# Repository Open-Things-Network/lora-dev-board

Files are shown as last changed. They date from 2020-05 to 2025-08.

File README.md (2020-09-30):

# lora-dev-board

Uniwersalna platforma sprzętowa ułatwiająca projektowanie i testowanie urządzeń IoT wykorzystujących do komunikacji sieć LoRaWAN.

## Cele projektu

* Udostępnienie gotowego do wykorzystania projektu płytki PCB
* Dostarczenie przykładowych szablonów aplikacji pozwalających na programowanie płytki przy użyciu Arduino SDK

## Założenia

Platforma została zaprojektowana tak, aby jej zbudowanie i uruchomienie było możliwe dla hobbystów posiadających podstawowe umiejętności w zakresie budowanie układów elektronicznych oraz programowania. Zgodnie z tym  przyjęto też dodatkowe założenia: 

* Zastosowanie popularnej płytki Arduino Pro Mini z mikrokontrolerem ATmega328P
* Współpraca z najczęściej stosowanymi układami nadawczo-odbiorczymi LoRa: RFM95W lub RN2483
* Wykorzystanie różnych źródeł zasilania, w tym standardowych baterii alkalicznych, baterii litowych oraz akumulatorów litowo-polimerowych lub litowo-jonowych
* Możliwość ładowania baterii litowo-polimerowych lub litowo-jonowych z wykorzystaniem paneli fotowoltaicznych małej mocy lub poprzez gniazdo USB

## Jak zacząć?

W `templates` znajdują się szablony aplikacji, które z pewnością ułatwią realizację własnych pomysłów, a folder `projects` zawiera przykłady projektów zrealizowanych z wykorzystaniem platformy **lora-dev-board**.

Poniższe punkty zostaną wkrótce uzupełnione opisami.

* Projekt płytki: [kompletacja elementów](https://github.com/Open-Things-Network/lora-dev-board/blob/master/v1.0/README.md#lista-elementów) i budowa urządzenia
* Uruchomienie bazowej aplikacji wysyłającej informacje o stanie urządzenia

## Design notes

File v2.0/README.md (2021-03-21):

# v2.0

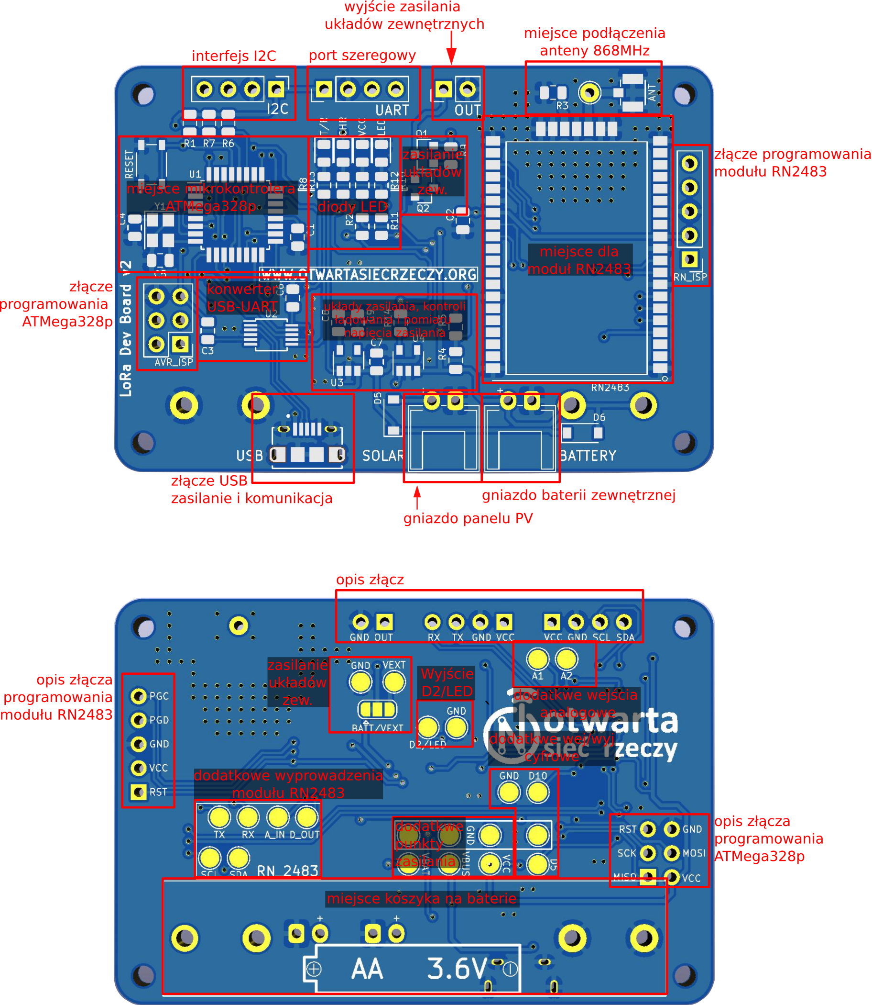
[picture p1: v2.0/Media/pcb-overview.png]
pcb overview


# Spis treści:
1. [Opis płytki](#Opis-płytki)
2. [Bootloader](#Bootloader)
3. [Interfejs LoRaWAN](#Interfejs-LoRaWAN)
4. [Układ zasilania](#Układ-zasilania)
5. [Układ ładowania](#Układ-ładowania)
6. [Diody LED](#Diody-LED)
7. [Interfejsy komunikacyjne](#Interfejsy-komunikacyjne)
8. [Złącza zasilania](#Złącza-zasilania)
9. [Pomiar napięcia baterii](#Pomiar-napięcia-baterii)
10. [Sterowanie zasilaniem układów zewnętrznych](#Sterowanie-zasilaniem-układów-zewnętrznych)
11. [Lista elementów](#Lista-elementów)
12. [Uwagi](#Uwagi)

# Opis płytki
Platforma deweloperska oparta na mikrokontrolerze ATMega328p. Na płytce znajduje się konwerter USB-UART dzięki czemu nie są wymagane dodatkowe układy komunikacyjne do programowania.
Do komunikacji z siecią LoRaWAN służy moduł RN2483.

## Bootloader
Do mikrokontrolera wgrany jest bootloader z Arduino Pro Mini za pomocą złącz programowania ISP, dzięki czemu można przygotować oraz wgrać program przez ARDIUNO IDE lub PLATFORMIO wykorzystując konwerter USB-UART.

## Interfejs LoRaWAN
Płytka pozwala na realizację interfejsu LoRaWAN za pomocą modułu z wbudowaną obsługą stosu LoRaWAN [RN2483A](https://www.microchip.com/wwwproducts/en/RN2483) - komunikacja z modułem poprzez port szeregowy obsługiwany programowo przez piny 10 (RX) i 11 (TX) mikrokontrolera ATMega328p (odpowiednio piny 6 i 7 zgodnie z Arduino Pro Mini).

## Układ zasilania
Zastosowany regulator napięcia LDO [AP2112K-3.3TRG1](https://cdn-shop.adafruit.com/product-files/2471/AP2112.pdf).
* Maksymalne napięcie zasilania - 6V
* Minimalne napięcie zasilania - 2.5V
* Spadek napięcia dla prądu 10mA - 5mV, 300mA - 125mV, 600mA - 250mV
* Napięcie wyjściowe - 3.3V
* Prąd maksymalny - 1A

## Układ ładowania
Zastosowany kontroler ładowania akumulatorów litowo-polimerowych (Li-Po) i litowo-jonowych (Li-Ion) [MCP73831](https://www.microchip.com/wwwproducts/en/en024903#additional-features).
* Maksymalne napięcie zasilania - 6V
* Minimalne napięcie zasilania - 3.75V
* Napięcie ładowania - 4.2V
* Prąd ładowania reguluje się przez dobranie R1, dla 2k&#x2126; - 500mA, 4k&#x2126; - 250mA

## Diody LED
|Oznaczenie|Opis|
|:---:|:---|
|T/R|dioda sygnalizująca komunikację USB-ATMEGA|
|CHR|sygnalizuje ładowanie podłączonej baterii Li-Po/Li-Ion|
|VCC|sygnalizuje obecność napięcia zasilania|
|LED|dioda do ogólnego zastosowania w aplikacji użytkownika (`USER_LED`)|

## Interfejsy komunikacyjne
Do podłączenia zewnętrznych czujników dostępne są interfejsy:
* I2C (na magistrali wlutowane są rezystory podciągające)
* port szeregowy obsługiwany programowo (z wykorzystaniem biblioteki `SoftwareSerial`) na pinach 12 (RX) i 13 (TX) ATMega328p (odpowiednio piny 8 i 9 zgodnie z Arduino Pro Mini).

## Złącza zasilania
Do płytki możemy podłączyć źródło zasilania:
* USB - złącze USB pełni funkcje zasilania płytki, źródła ładowania baterii oraz komunikację z mikrokontrolerem.
* BATTERY - złącze baterii/akumulatorów Li-Po/Li-Ion 3,6V, do złącza podłczony jest kontoler ładowania akumulatorów.
* KOSZYK - miejsce na koszyk baterii/akumulatorów Li-Po/Li-Ion o rozmiarze AA (14500) 3,6V, do złącza podłczony jest kontoler ładowania akumulatorów.
* SOLAR - może służyć jako źródło zasilania, ale najlepiej można go wykorzystać wraz z ogniwem jako źródło ładowania akumulatora. Należy wykorzystać panel o napięciu 5,5V.

> **UWAGA!** Przy wykorzystaniu baterii litowych (FR6) nie ładowalnych należy wylutować kontroler ładowania akumulatorów U4.

## Pomiar napięcia baterii
Wykorzystane wejście analogowe A0 i dzielnik napięcia R4, R5 (makro `VBAT`).

## Sterowanie zasilaniem układów zewnętrznych
Układ sterowania jest złożony z dwóch tranzystorów. Pierwszy tranzystor NPN BC817 jest wysterowany z mikrokontrolera i wykorzystany jest do kluczowania drugiego tranzystora. Tranzystor polowy z kanałem typu P pozwala na sterowanie zasilaniem zewnętrznego urządzenia. Wybór zasilania dla zewnętrznego urządzenia dokonuje się zworką JP5(BATT/VEXT). Możemy zasilać urządzenie z stabilizowanego zasilania 3.3V lub zasilanie podać z zewnątrz (lub innego punktu), wymaga to podłączenia napięcia na pad VEXT oraz rozcięcie zworki JP5 i zalutowaniu jej w pozycji EXT. Zastosowany tranzystor polowy YJL2301F pozwala na obciążenie do 2A z źródła zewnętrznego oraz 600mA z VCC (ograniczenia wynikają z parametrów LDO). 

# Lista elementów
| Oznaczenie | Element | Obudowa | Ilość na PCB |
|:-----:|:---|:---|:--|
|KOSZYK|2915 keystone|n.d.|2|
|C1-C3;C6|100nF|0805|4|
|C4-C5|22pF|0805|2|
|C7|1uF|0805|1|
|C8|n.d.|0805|1|
|D1|LED YELLOW|0805|1|
|D2|LED GREEN|0805|1|
|D3|LED RED|0805|1|
|D4|LED BLUE|0805|1|
|D5-D6|1N5819|SOD-123|2|
|J1|u.FL|n.d.|1|
|J2;J5|PinHeader|1x04|2|
|J3|PinHeader|2x03|1|
|J4|PinHeader|1x05|1|
|J6|PinHeader|1x02|1|
|J7-J8|JST|PH-S2B|2|
|J9|USB|10118194-0001LF AMPHENOL|n.d.|1|
|Q1|YJL2301F|SOT-23|1|
|Q2|BC817|SOT-23|1|
|R1-R2;R6-R7;R9|10k|0805|5|
|R3|50R|0805|1|
|R5|33k|0805|1|
|R8;R10-R13|1k|0805|5|
|R14|4k|0805|1|
|SW1|SKRPACE010|n.d.|1|
|U1|ATMega328p-AU|TQFP-32|1|
|U2|CH340E|MSOP-10|1|
|U3|AP2112K-3.3|SOT-23-5|1|
|U4|MCP73831-2-OT|SOT-23-5|1|
|Y1|16MHz|3225|1|

# Uwagi
Na pierwszych wersjach płytki pojawił się błąd w opisie elementów Q1 i Q2. Każdy kto otrzyma taką wersję płytki zostanie o tym poinformowany.

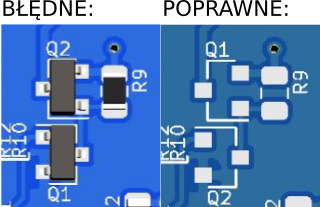
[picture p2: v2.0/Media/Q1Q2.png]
Front Silk Update


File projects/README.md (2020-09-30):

Projekty zrealizowane z wykorzystaniem platformy lora-dev-board.

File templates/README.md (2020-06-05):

# Szablony aplikacji

Zastosowanie szablonów ma na celu przyspieszenie procesu tworzenia własnych aplikacji. Wystarczy dokonać wstępnej parametryzacji i skupić się na implementacji docelowych funkcjonalności. Szablony aplikacji zapewniają realizację komunikacji LoRaWAN, wprowadzanie układu w stan uśpienia oraz ułatwiają wykorzystanie zasobów platformy w wybranym wariancie konfiguracji. 

Dostępne wersje szablonów:
* `lorawan-rfm-template.ino` - dla wariantu 1 konfiguracji (Arduino Pro Mini i RFM95W)
* `lorawan-rn-template.ino` - dla wariantu 2 konfiguracji (Arduino Pro Mini i RN2483A)

## Wymagania związane z oprogramowaniem
Wykorzystane biblioteki:
* [Arduino-LMIC Library](https://github.com/matthijskooijman/arduino-lmic)
* [Low Power Library for Arduino](https://github.com/rocketscream/Low-Power)
* [Cayenne LPP](https://github.com/ElectronicCats/CayenneLPP) lub [The Things Network Arduino Library](https://github.com/TheThingsNetwork/arduino-device-lib), która zawiera CayenneLPP i jest również używana do komunikacji z RN2483A

## Komunikacja LoRaWAN
### Zastosowanie RFM95W
Komunikacja mikrokontrolera z układem SX1276 (nadajnik-odbiornik LoRa), który znajduje się na płytce RFM95W jest realizowana poprzez interfejs SPI. Szczegółowe informacje dotyczące transceivera SX1276 można znaleźć w [dokumentacji układu](https://semtech.my.salesforce.com/sfc/p/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).

Moduł RFM95W jest połączony z Arduino Pro Mini w następujący sposób:

|RFM95W|Arduino Pro Mini|
|:----:|:---:|
|MOSI|11 (MOSI)|
|MISO|12 (MISO)|
|SCK|13 (SCK)|
|NSS|10|
|RESET|4|
|DIO0|5|
|DIO1|7|
|DIO2|6 (opcja - patrz JP3)|

Za realizację stosu LoRaWAN odpowiada biblioteka [Arduino-LMIC Library](https://github.com/matthijskooijman/arduino-lmic).

Pierwszym krokiem jest poinformowanie biblioteki, które piny Arduino zostały użyte do realizacji komunikacji z transceiverem.
Mapowanie pinów zgodnie z przedstawioną powyżej listą połączeń:
```c
const lmic_pinmap lmic_pins = {
    .nss = 10,
    .rxtx = LMIC_UNUSED_PIN,
    .rst = 4,
    .dio = { 5, 7, LMIC_UNUSED_PIN }, // lub { 5, 7, 6 } jeśli ma być wykorzystany również DIO2
};
```
> LMIC potrzebuje dostępu do DIO0, DIO1 i opcjonalnie DIO2. Wykorzystanie DIO2 dotyczy tylko pracy z modulacją FSK. W przypadku modulacji LoRa używane są DIO0 i DIO1.

Kolejnym krokiem jest przekazanie informacji o sposobie aktywacji urządzenia w sieci.
W szablonie użyto aktywacji według personalizacji (ABP - *Activation By Personalization*). Jest to najprostszy sposób aktywacji wykorzystywany do realizacji urządzenia podłączonego na stałe do jednej wybranej sieci. Urządzenie jest gotowe do pracy zaraz po rejestracji w sieci. Proces rejestracji urządzenia w sieci The Things Network jest dobrze opisany w [dokumentacji](https://www.thethingsnetwork.org/docs/devices/registration.html). Podczas rejestracji należy pamiętać o wybraniu metody aktywacji ABP.

Urządzenie posiada stały adres (*Device Address*) i zestaw kluczy sesyjnych wykorzystywanych do sprawdzania integralności wiadomości w warstwie sieci (*Network Session Key*) oraz do szyfrowania danych w warstwie aplikacji (*Application Session Key*). Urządzenie jest więc aktywowane na etapie personalizacji i zarówno adres urządzenia, jak i klucze sesji nie zmieniają się przez cały czas pracy urządzenia.<br>
Informacje uzyskane podczas rejestracji urządzenia należy wstawić w miejsce właściwych stałych:
```c
static const PROGMEM u1_t NWKSKEY[16] = { 0x00, 0x00, 0x00, 0x00, 0x00, 0x00, 0x00, 0x00, 0x00, 0x00, 0x00, 0x00, 0x00, 0x00, 0x00, 0x00 };
static const PROGMEM u1_t APPSKEY[16] = { 0x00, 0x00, 0x00, 0x00, 0x00, 0x00, 0x00, 0x00, 0x00, 0x00, 0x00, 0x00, 0x00, 0x00, 0x00, 0x00 };
static const u4_t DEVADDR = 0x00000000;
```
Stosowanie ABP jest mniej bezpieczne i nie jest zlecane również ze względu na ograniczenia funkcjonalne, lecz brak konieczności nawiązywania i sprawdzania połączenia z siecią może być w pewnych zastosowaniach zaletą. 

Komunikacja bezprzewodowa urządzenia z bramkami LoRaWAN odbywa się w kanałach, których środek wyznaczają ściśle określone częstotliwości. Zwykle używa się ośmiu kanałów o szerokości 125kHz, z których trzy są obowiązkowe i niezależne od sieci, a pozostałe są opcjonalne i mogą być określone indywidualnie dla każdej sieci, przy zachowaniu właściwej separacji i zasad określonych w zaleceniach dotyczących pasma.<br>
W przypadku sieci TTN stosowane są następujące kanały:
```c
// obowiązkowe
LMIC_setupChannel(0, 868100000, DR_RANGE_MAP(DR_SF12, DR_SF7), BAND_CENTI); 
LMIC_setupChannel(1, 868300000, DR_RANGE_MAP(DR_SF12, DR_SF7), BAND_CENTI); 
LMIC_setupChannel(2, 868500000, DR_RANGE_MAP(DR_SF12, DR_SF7), BAND_CENTI); 
// dodatkowe
LMIC_setupChannel(3, 867100000, DR_RANGE_MAP(DR_SF12, DR_SF7), BAND_CENTI); 
LMIC_setupChannel(4, 867300000, DR_RANGE_MAP(DR_SF12, DR_SF7), BAND_CENTI);
LMIC_setupChannel(5, 867500000, DR_RANGE_MAP(DR_SF12, DR_SF7), BAND_CENTI); 
LMIC_setupChannel(6, 867700000, DR_RANGE_MAP(DR_SF12, DR_SF7), BAND_CENTI);
LMIC_setupChannel(7, 867900000, DR_RANGE_MAP(DR_SF12, DR_SF7), BAND_CENTI);
```
Jest jeszcze jeden dedykowany kanał (869.525MHz) o szerokości 125kHz, który służy tylko do przesyłania informacji w kierunku do urządzenia (*downlink*) w tzw. drugim oknie odbiorczym RX2. 
Parametry transmisji w tym kanale są stałe i ustawione domyślnie na SF12, czyli DR0 (*Data Rate 0*). W przypadku sieci TTN parametr ten powinien być zmieniony na SF9 (DR2):
```c 
LMIC.dn2Dr = DR_SF9;
```
To wystarczy żeby rozpocząć komunikację z wykorzystaniem The Things Network - otwartej sieci LoRaWAN.

LMIC oferuje prosty model programowania oparty na zdarzeniach, w którym wszystkie zdarzenia protokołu są wysyłane do funkcji zwrotnej `onEvent()`.
W tym modelu cały kod aplikacji jest uruchamiany w tak zwanych zadaniach (funkcjach), które są wykonywane w głównym wątku za pomocą harmonogramu `os_runloop_once()`. Do zarządzania zadaniami wymagana jest dodatkowa struktura typu `osjob_t`, która identyfikuje zadanie i przechowuje informacje kontekstowe. Przykładem zadania w opisywanym szablonie jest funkcja `do_send()` odpowiadająca za przygotowanie i  wysyłanie danych. Zadanie to jest wykonywane cyklicznie co określony interwał (`TX_INTERVAL`). Wysyłanie danych z urządzenia do sieci jest inicjowane wywołaniem funkcji `LMIC_setTxData2()`. Zakończenie wysyłania danych jest sygnalizowane wystąpieniem zdarzenia `EV_TXCOMPLETE` obsługiwanego w `onEvent()`. W tym miejscu planowane jest kolejne wykonanie zadania poprzez wywołanie `os_setTimedCallback()`. Można również sprawdzić, czy zostały odebrane informacje zwrotne przesłane z sieci do urządzenia.    

Wywołanie poniższej funkcji powoduje kompensację błędów zegara i opóźnień wprowadzanych przez program, co w rezultacie zwiększa szansę odebrania informacji zwrotnej przesyłanej do urządzenia w wyznaczonych oknach czasowych (dokładny opis problemu znajduje się w [dokumentacji LMIC](https://github.com/matthijskooijman/arduino-lmic#timing)).
```c 
LMIC_setClockError(MAX_CLOCK_ERROR * 1 / 100);
```

Ustawianie parametru DR (*Data Rate*) oraz mocy nadajnika umożliwia funkcja `LMIC_setDrTxpow()`. Przykład użycia tej funkcji w celu ustawienia DR0 (SF7) i mocy nadajnika na poziomie 14dBm (czyli 25mW):
```c
LMIC_setDrTxpow(DR_SF7, 14);
```

Fragment kodu przedstawiony poniżej wyłącza tryb sprawdzania połączenia z siecią, który w przypadku ABP nie ma praktycznie zastosowania.
```c
LMIC_setLinkCheckMode(0);
```

Jeśli aplikacja wykorzystuje ABP, a urządzenie nie pracuje w klasie B, to warto zaoszczędzić trochę zasobów wyłączając część kodu odpowiedzialną za obsługę nieużywanych funkcjonalności. Można tego dokonać poprzez odkomentowanie następujących definicji w pliku `src/lmic/config.h` biblioteki LMIC:
```c
// Uncomment this to disable all code related to joining
#define DISABLE_JOIN
// Uncomment this to disable all code related to ping
#define DISABLE_PING
// Uncomment this to disable all code related to beacon tracking.
// Requires ping to be disabled too
#define DISABLE_BEACONS
```
W ten sposób można zyskać nawet kilka kilobajtów pamięci programu. Dzięki temu można również usunąć z aplikacji nieużywane funkcje (ich brak nie będzie już generował błędów podczas kompilacji):
```c
void os_getArtEui (u1_t* buf) { }
void os_getDevEui (u1_t* buf) { }
void os_getDevKey (u1_t* buf) { }
```
### Zastosowanie RN2483
Do uzupełnienia.
## Interwał wysyłania danych
Czas pomiędzy kolejnymi próbami wysyłania danych do sieci LoRaWAN (*uplink*) określa stała `TX_INTERVAL`. Wartość domyślna, to 60 sekund. 
```c
const unsigned TX_INTERVAL = 60;
```
Należy pamiętać o obowiązujących ograniczeniach dotyczących zajętości pasma. Zasady dostępu do kanału (tzw. cykl pracy nadajnika - *Duty Cycle*) oraz dopuszczalna moc sygnału nadawanego są ściśle określone w stosownych normach. W Europie sposób wykorzystania pasma otwartego 868MHz określa norma ETSI EN 300 220.<br>
Zarówno LMIC, jak i stos LoRaWAN zaimplementowany w układzie RN2483A uwzględniają te ograniczenia, a każda próba wysłania wiadomości, która narusza zasady zakończy się błędem (`no_free_ch` w przypadku RN2483A).<br>
W sieci The Things Network obowiązują również dodatkowe limity związane z czasem nadawania (tzw. *Fair Access Policy*). 

Wszystkie te ograniczenia są opisane w [dokumentacji TTN](https://www.thethingsnetwork.org/docs/lorawan/duty-cycle.html).

## Rodzaj i format danych
W szablonach został wykorzystany popularny sposób kodowania danych [Cayenne LPP (*Low Power Payload*)](https://developers.mydevices.com/cayenne/docs/lora/#lora-cayenne-low-power-payload), który znacząco upraszcza przygotowanie i wysyłanie danych. Wadą stosowania Cayenne LPP jest zwiększony rozmiar przesyłanych danych, ponieważ do każdej wartości dodawane są informacje określające identyfikator kanału oraz typ danych.

Przykład użycia Cayenne LPP:
```c
#include <CayenneLPP.h>
```
* utworzenie bufora o długości 51 bajtów
```c
CayenneLPP lppdata(51);
```
* wyczyszczenie bufora i dodanie pierwszej wartości (w tym przypadku wartość napięcia baterii, kanał 1)
```c
lppdata.reset();
lppdata.addAnalogInput(1, VBAT);
```
> Podstawowa wersja Cayenne LPP umożliwia kodowanie jedynie 12 typów danych. Jeśli brakuje typu odpowiedniego dla określonej wielkości mierzonej, to można zastosować wejście analogowe (`LPP_ANALOG_INPUT`). Takie rozwiązanie zostało wykorzystane w szablonach do przesyłania wartości napięcia elektrycznego. 
* wysłanie danych z wykorzystaniem `getBuffer()` i `getSize()` w celu wskazania miejsca przechowywania i określenia ilości danych
```c
LMIC_setTxData2(1, lppdata.getBuffer(), lppdata.getSize(), 0); 
```
Odbierane dane mogą być automatycznie dekodowane po stronie aplikacji zdefiniowanej w TTN bez konieczności tworzenia własnego dekodera (wystarczy zmienić **Payload Format** z `Custom` na `Cayenne LPP`).<br>
Przykład zdekodowanej wiadomości:
```
{
  "analog_in_1": 3.77
}
```
Zastosowanie dyrektywy
```c
#define JUST_SEND_HELLO
```
powoduje, że urządzenie wysyła tylko wiadomość o treści `"Hello!"`. 
## Oszczędzanie energii
Szablony zawierają przykład prostej realizacji wprowadzania urządzenia w stan uśpienia w celu wydłużenia czasu pracy na baterii. Do tego celu wykorzystana została popularna biblioteka [Low Power](https://github.com/rocketscream/Low-Power) dla Arduino, która jest bardzo łatwa w użyciu dla początkującego programisty. Biblioteka dostarcza zestaw metod służących do wprowadzania mikrokontrolera w określony tryb uśpienia (*Sleep Mode*) z możliwością wyłączenia poszczególnych jego komponentów na określony czas. 
```c
#include <LowPower.h>
```
Włączenie trybu oszczędzania energii w programie odbywa się poprzez zastosowanie dyrektywy `SAVE_ENERGY`.
```c
#define SAVE_ENERGY
``` 
W programie wykorzystano metodę `powerDown()`, która wprowadza mikrokontroler w stan wyłączenia (*Power Down*). Jest to tryb maksymalnego oszczędzania energii, w którym wykorzystywana jest minimalna liczba zintegrowanych układów peryferyjnych potrzebna do wznowienia pracy mikrokontrolera - w tym przypadku przerwanie z WDT (*Watchdog Timer*). Wywołanie tej metody z parametrami jak poniżej powoduje wyłączenie mikrokontrolera na czas 8 sekund.
```c
LowPower.powerDown(SLEEP_8S, ADC_OFF, BOD_OFF);
```
## Wykorzystanie zasobów platformy
### Pomiar napięcia baterii
Napięcie baterii zostało doprowadzone do dzielnika napięcia, którego wyjście jest podłączone do wejścia analogowego A0 modułu Arduino Pro Mini. Makro `VBAT` zwraca wartość napięcia baterii wyrażoną w woltach. 
```c
#define VBAT (analogRead(A0) * 0.00424568)
```
Zastosowana stała wynika z wartości rezystancji użytych do budowy dzielnika oraz wartości napięcia wewnętrznego źródła referencyjnego. 
### Obsługa portu szeregowego
Oprócz sprzętowego portu szeregowego modułu Arduino Pro Mini (używanego również do programowania i debugowania), płytka udostępnia dodatkowy port obsługiwany programowo dzięki zastosowaniu standardowej biblioteki `SoftwareSerial`. Port ten jest podpięty pod piny 8 (RX) i 9 (TX) Arduino Pro Mini. Wyprowadzenie sygnałów na złącze J3 (UART) pozwala na podłączenie dodatkowych urządzeń zewnętrznych (np. odbiornika GPS).

```c
SoftwareSerial userSerial(8, 9); // GPSP available on J3 (RX, TX)  
...
userSerial.begin(9600);
```
### Wykorzystanie diody LED
Na płytce można zamontować dodatkową diodę LED podłączoną do pinu 2 Arduino Pro Mini.
```c
#define USER_LED 2 // additional LED
```
Dioda ta może być wykorzystana w aplikacji w dowolny sposób.
W prezentowanych szablonach służy jako wskaźnik komunikacji LoRaWAN - jest włączana przed zainicjowaniem wysyłania danych i wyłączana po zakończeniu cyklu transmisji i odbioru danych. 

Sterowanie diodą LED:
```c
pinMode(USER_LED, OUTPUT);
...
digitalWrite(USER_LED, HIGH);
digitalWrite(USER_LED, LOW);
```
### Sterowanie zasilaniem układów zewnętrznych
Układ zasilania urządzeń zewnętrznych zbudowany z tranzystorów Q1 i Q2 został podłączony do pinu 3 modułu Arduino Pro Mini. Układ ten zapewnia odpowiednią wydajność prądową, a także umożliwia sterowanie obecnością napięcia na padach TP5 (VOUT) i TP6 (GND). W zależności od zworki JP9 będzie to napięcie z układu regulatora (VCC) lub napięcie baterii (VBAT). 

Sterowanie zasilaniem urządzeń zewnętrznych z poziomu aplikacji odbywa się poprzez ustawianie odpowiedniego stanu na wyjściu `VOUT_ENABLE`. 
```c
#define VOUT_ENABLE 3 
```
Przykład realizacji sterowania:
```c
pinMode(VOUT_ENABLE, OUTPUT);
...
digitalWrite(VOUT_ENABLE, HIGH);
digitalWrite(VOUT_ENABLE, LOW);
```

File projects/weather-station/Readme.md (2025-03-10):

# Stacja pogody

*For English version go [here](Readme_eng.md)*

Projekt bazuje na kodzie napisanym na platformie arduino w pliku `weather-station.ino`. Wykorzystuje wersję v2.0 płytki PCB.
Aby skonfigurować projekt należy edytowac zmienne `appEui` oraz `appKey` zgodnie z ustawieniami sieci TTN. Transceiver będzie korzystał z trybu OTAA.

## Kompilacja i wgrywanie

Kompilację projektu wykonuje się poprzez Arduino IDE. Aby wgrać kod na płytkę należy skorzystac z gniazda USB znajdującego się na płytce PCB.

## Obudowa

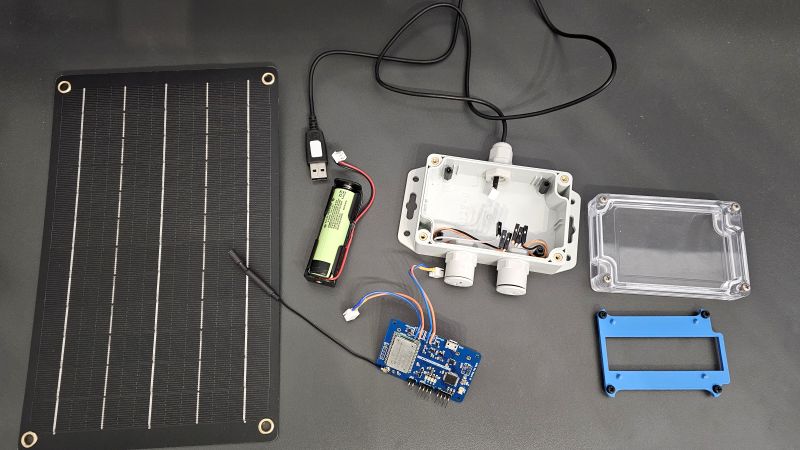
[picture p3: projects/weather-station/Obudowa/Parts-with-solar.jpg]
Obudowa


Lista części: 
- Obudowa: Kradex Z128
- Panel słoneczny: DFRobot FIT0601
- Czujniki: DS18B20 & BME280
- Bateria: Panasonic NCR18650B
- Inne części:
    - Dławnice kablowe M12 x3
    - Dystanse 12 mm x4
- Antena: 868 Mhz w kształcie sprężyny ze złączem U.FL.

Dodatkowo potrzebny jest wydruk 3D, na którym umieszczona jest płytka PCB wewnątrz obudowy (niebieska część na zdjęciu).

## Złożenie

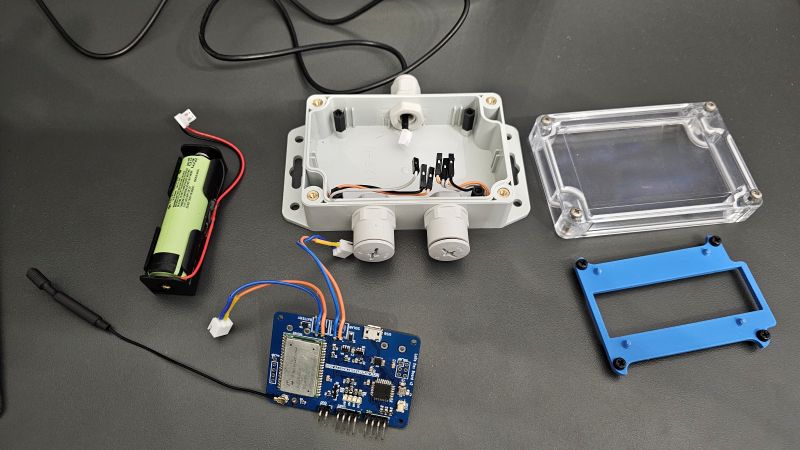
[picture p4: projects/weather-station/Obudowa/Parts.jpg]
Obudowa w częściach


1. Usuń wzystkie wypustki z obudowy, które będą przeszkadzały w umieszczeniu dławnic w obudowie.
2. Zrób otwory pod dławnice (jak na zdjęciu powyżej). W nakrętkach dławnic wywierć otwory, aby powietrze mogło się dostać do czujników.
3. Umieść dystanse w obudowie.
4. Umieść dławnice w obudowie. Wewnątrz nich umieść czujniki, będzie wystarczająco miejsca nawet na BME280.
5. Włóż baterię na spód obudowy.
6. Przykręć wydrukowaną część do dystansów.
7. Umieść płytkę PCB.
8. Poprowadź kable w sposób umożliwiający zamknięcie obudowy.

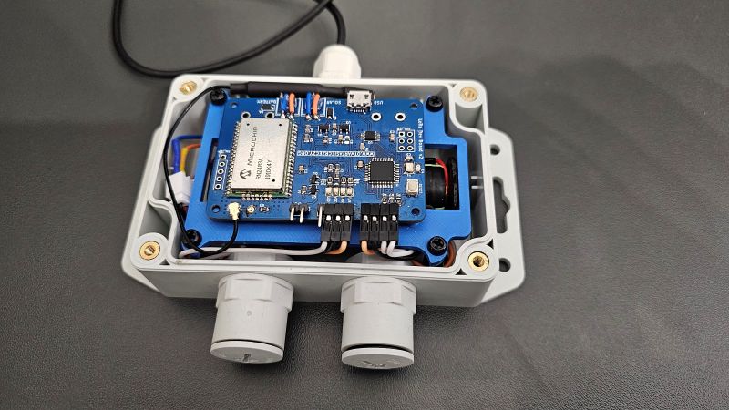
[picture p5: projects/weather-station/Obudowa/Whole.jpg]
Złożona obudowa


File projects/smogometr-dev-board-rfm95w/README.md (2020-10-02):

# Smogometr z czujnikami środowiskowymi
Celem projektu jest zaprezentowane możliwości płytki deweloperskiej [OTN](https://github.com/Open-Things-Network/lora-dev-board/tree/master/v1.0) oraz zbudowanie prostej klatki meteorologicznej. Zadaniem urządzenia jest pomiar pyłu zawieszonego (PM10 i PM2,5), temperatury, ciśnienia, wilgotności oraz natężenia światła i wysłanie danych używając technologii LoRa.

Smogometr

## Zastosowane urządzenia
 * Arduino Pro Mini (odpowiednik) - 3,3V ATmega328P
 * Moduł radiowy LoRa 868MHz RFM95W
 * Moduł GY-302 z czujnikiem oświetlenia BH1750
 * Czujnik ciśnienia, wilgotności i temperatury Bosch BME280
 * Czujnik pyłu zawieszonego Nova Fitness SDS011
 * Moduł przetwornicy DC-DC Step-up 2.5..5V - 5V U3V12F5
 * Akumulator Li-Po Akyga 3,7V/500mAh
 * Panel słoneczny 136 x 110 mm o mocy 2W
 * Antena 868MHz ze złączem U.FL

## Biblioteki do czujników
 * [Adafruit BME280 Library by Adafruit](https://github.com/adafruit/Adafruit_BME280_Library)
 * [BH1750 by Christopher Laws](https://github.com/claws/BH1750)
 * [SDS by Otwarta Sieć Rzeczy](https://github.com/Open-Things-Network/workshops/tree/master/smogometr/libraries/sds)

## Opis połaczeń
Czujnik SDS przesyła dane przez złącze szeregowe i jest zasilany poprzez przetwornicę napięciem 5V, natomiast pozostałe czujniki są zasilane bezpośrednio z płytki napięciem 3,3V i wykorzustują magistralę I2C. 

## Budowa klatki meteorologicznej
Klatka meteorologiczna została zbudowana na bazie drewnianych drzwiczek ażurowych i desek dostępnych w markecie budowlanym. Klatka wymaga zwiększenia kąta nachylenia dachu, na którym umieszczony zostanie panel słoneczny oraz zabezpieczenie jej powierzchni przed deszczem i wilgocią.

Przed:
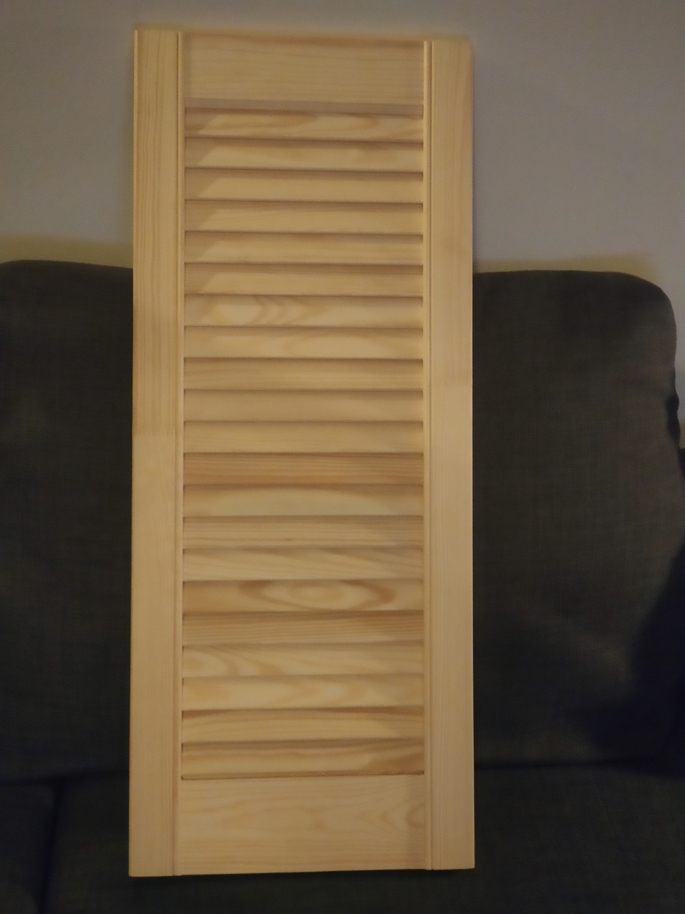
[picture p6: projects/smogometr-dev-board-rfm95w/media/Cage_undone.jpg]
Drzwiczki ażurowe
<br>

Po:
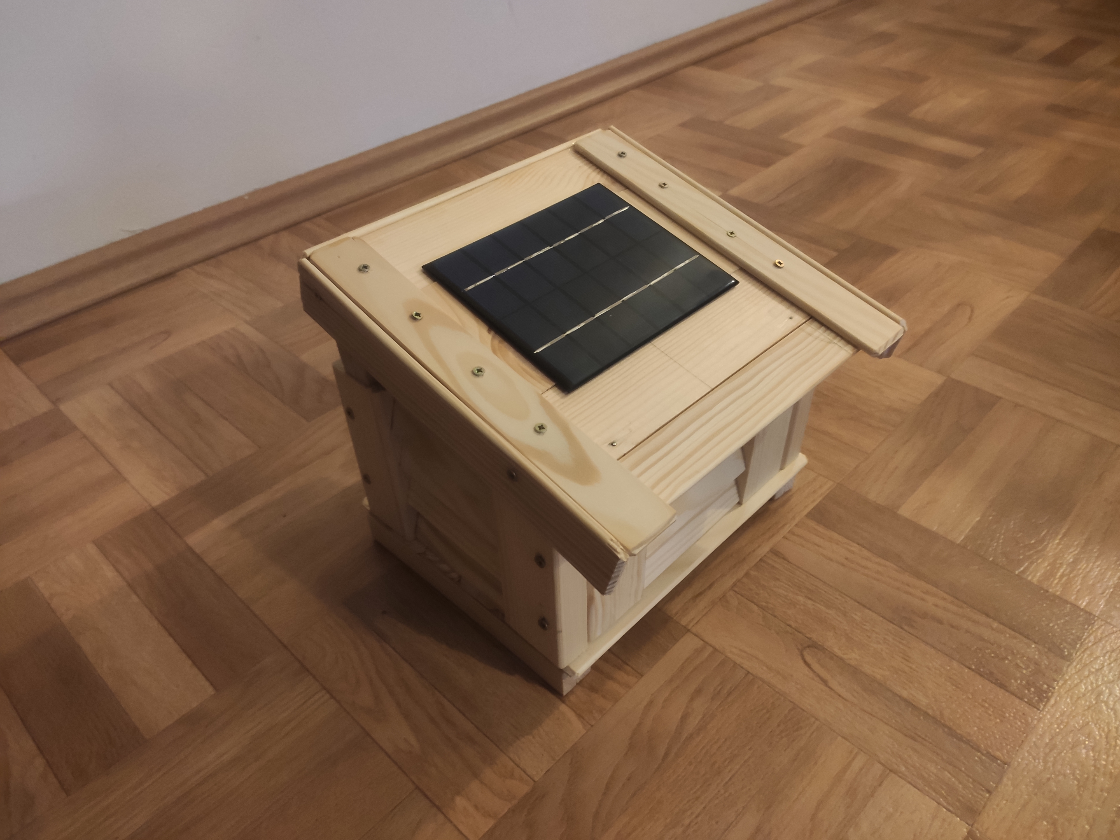
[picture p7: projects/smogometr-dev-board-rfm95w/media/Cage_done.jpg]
Amatorska klatka stevensona
<br>

## [Dodatkowe zdjęcia](media/)

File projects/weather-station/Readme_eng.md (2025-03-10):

# Weather station

Project is based on the Arduino code and placed in the `weather-station.ino`. It uses version v2.0 of the hardware.
To configure the project edit `appEui` and `appKey` variables according to TTN settings. The tranceiver will work in the OTAA mode.

## Compiling and uploading

To compile follow the standard procedure of Arduino IDE.
To upload plug the usb cable into pcb and upload the code from Arduino IDE.

## Case

Case

Parts list:
- Case: Kradex Z128
- Solar panel: DFRobot FIT0601
- Sensors: DS18B20 & BME280
- Battery: Panasonic NCR18650B
- Other parts:
    - Cable glands M12 x3
    - PCB spacers 12 mm x4
- Antenna: 868 Mhz spring antenna with U.FL connector.

In addition, there is a 3D print that secures PCB inside the case (blue part on the picture).

## Assembly

Whole case

The process of assembly is quite easy, but some modifications must be made: 

1. Get rid of Kradex's unnecessary tabs, that will interfere with cable glands.
2. Make holes for cable glands. Make a hole in the glands' nut to provide air to sensors.
3. Mount the spacers.
4. Mount the cable glands. Place sensors inside them, there will be enough space even for the BME
5. Place the battery at the bottom.
6. Place the 3D-printed base onto the spacers and screw it in place.
7. Place the PCB.
8. Route the cables.

Whole case

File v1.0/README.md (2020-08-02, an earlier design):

# v1.0

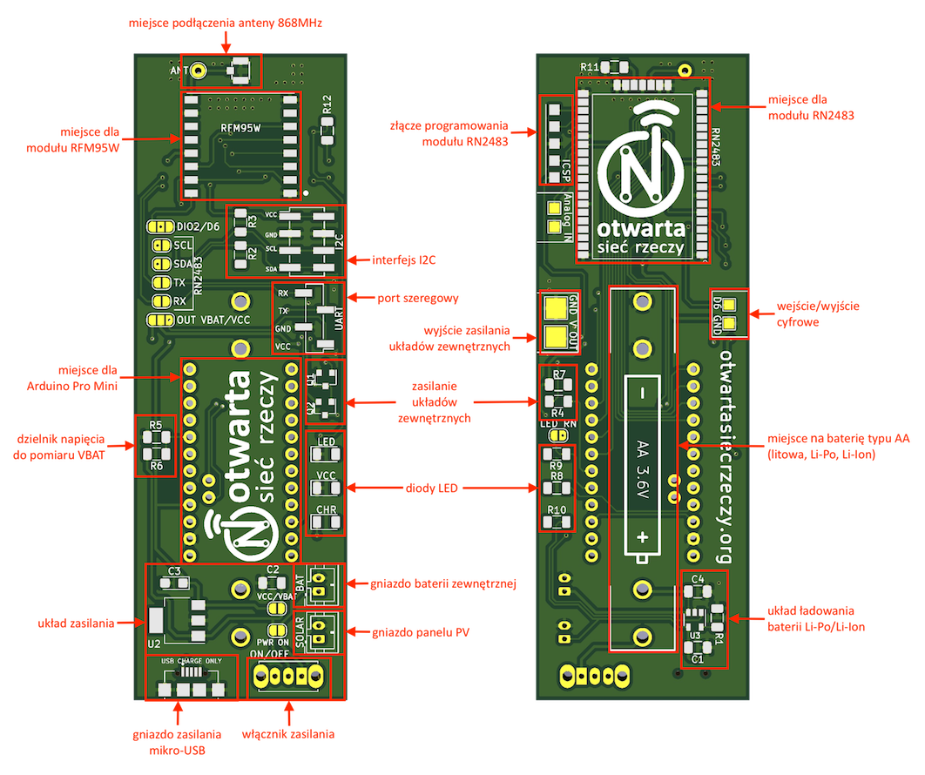
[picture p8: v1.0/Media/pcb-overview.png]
pcb overview


# Spis treści:
1. [Opis płytki](#Opis-płytki)
2. [Arduino Pro Mini](#Arduino-Pro-Mini)
3. [Interfejs LoRaWAN](#Interfejs-LoRaWAN)
4. [Układ zasilania](#Układ-zasilania)
5. [Układ ładowania](#Układ-ładowania)
6. [Diody LED](#Diody-LED)
7. [Interfejsy komunikacyjne](#Interfejsy-komunikacyjne)
8. [Pomiar napięcia baterii](#Pomiar-napięcia-baterii)
9. [Sterowanie zasilaniem układów zewnętrznych](#Sterowanie-zasilaniem-układów-zewnętrznych)
10. [Zworki](#Zworki)
11. [Lista elementów](#Lista-elementów)
12. [Uwagi](#Uwagi)

# Opis płytki
Możliwe warianty konfiguracji:
1. Arduino Pro Mini i RFM95W 
2. Arduino Pro Mini i RN2483A
3. RN2483A

Szczegółowe instrukcje dla wersji montażowych:
* Wersja minimalna [doc/A_minimal.md](doc/A_minimal.md)

## Arduino Pro Mini
Platforma współpracuje z modułami [Arduino Pro Mini](https://github.com/sparkfun/Arduino_Pro_Mini_328) lub ich klonami w obu wariantach (3.3V/8MHz i 5V/16MHz).
> **UWAGA!** Do programowania potrzebny jest konwerter USB/Serial.

## Interfejs LoRaWAN
Płytka pozwala na realizację interfejsu LoRaWAN na dwa różne sposoby:
* wykorzystanie modułu nadajnika-odbiornika LoRa [RFM95W](https://www.hoperf.com/modules/lora/RFM95.html) i implementacja stosu LoRaWAN na mikrokontrolerze - komunikacja z modułem poprzez SPI (piny 11, 12 i 13 Arduino Pro Mini)
* zastosowanie modułu z wbudowaną obsługą stosu LoRaWAN [RN2483A](https://www.microchip.com/wwwproducts/en/RN2483) - komunikacja z modułem poprzez port szeregowy obsługiwany programowo (piny 6 (RX) i 7 (TX) Arduino Pro Mini).

## Układ zasilania
Zastosowany regulator napięcia LDO [TS2940CW33](https://www.taiwansemi.com/en/products/details/TS2940CW33).
* Maksymalne napięcie zasilania - 26V
* Minimalne napięcie zasilania - 3.5V
* Spadek napięcia dla prądu 100mA - 100mV, 800mA - 600mV
* Napięcie wyjściowe - 3.3V
* Prąd maksymalny - 1A

> **UWAGA!** Do zasilania urządzenia wymagana jest bateria lub zasilacz podłączony do zacisków baterii (nie dotyczy wariantu zasilania B - patrz [Lista elementów](#Lista-elementów)).

## Układ ładowania
Zastosowany kontroler ładowania akumulatorów litowo-polimerowych (Li-Po) i litowo-jonowych (Li-Ion) [MCP73831](https://www.microchip.com/wwwproducts/en/en024903#additional-features).
* Maksymalne napięcie zasilania - 6V
* Minimalne napięcie zasilania - 3.75V
* Napięcie ładowania - 4.2V
* Prąd ładowania reguluje się przez dobranie R1, dla 2k&#x2126; - 500mA, 4k&#x2126; - 250mA

> **UWAGA!** Złącze microUSB służy tylko do ładowania baterii. Podanie zasilania przez złącze microUSB przy zamontowanym układzie ładowania i bez baterii spowoduje nieprawidłowe działanie urządzenia.

## Diody LED
|Oznaczenie|Opis|
|:---:|:---|
|LED|dioda do ogólnego zastosowania w aplikacji użytkownika (`USER_LED`)|
|VCC|sygnalizuje obecność napięcia zasilania|
|CHR|sygnalizuje ładowanie podłączonej baterii Li-Po/Li-Ion|

## Interfejsy komunikacyjne
Do podłączenia zewnętrznych czujników dostępne są interfejsy:
* I2C wyprowadzony bezpośrednio z Arduino Pro Mini (istnieje możliwość zastosowania rezystorów podciągających R2 i R3)
* port szeregowy obsługiwany programowo (z wykorzystaniem biblioteki `SoftwareSerial`) na pinach 8 (RX) i 9 (TX) Arduino Pro Mini.

## Pomiar napięcia baterii
Wykorzystane wejście analogowe A0 i dzielnik napięcia R5, R6 (makro `VBAT`).

## Sterowanie zasilaniem układów zewnętrznych
Układ sterowania jest złożony z dwóch tranzystorów. Pierwszy tranzystor NPN BC817 jest wysterowany z mikrokontrolera i wykorzystany jest do kluczowania drugiego tranzystora. Tranzystor polowy z kanałem typu P pozwala na sterowanie zasilaniem zewnętrznego urządzenia. Wybór zasilania dla zewnętrznego urządzenia dokonuje się zworką JP9. Możemy zasilać urządzenie z baterii lub stabilizowanego zasilania 3.3V. Zastosowany tranzystor polowy YJL2301F pozwala na obciążenie do 2A z baterii oraz 1A z VCC (ograniczenia wynikają z parametrów LDO). 

> **UWAGA!** Aby poprawnie sterować oraz zasilać przetwornice np. Pololu S7V7F5z ww. układu zworkę JP9 należy zalutować w pozycji VBAT.

## Zworki
|Symbol|Nazwa|Przeznaczenie|
|:----:|:---:|:---|
|JP4|PWR ON|Pozwala na ominięcie mechanicznego włącznika zasilania SW1 (zasilanie zawsze włączone)|
|JP2|VCC/VBAT|Pozwala na ominięcie regulatora napięcia LDO i bezpośrednie podanie napięcia z baterii na VCC Arduino|
|JP9|OUT VBAT/VCC|Wybór źródła zasilania układów zewnętrznych - bateria lub regulator napięcia|
|JP3|DIO2/D6|Sposób wykorzystania pinu 6 Arduino (jako DIO2 do transceivera w **RFM95W** lub wejście/wyjście ogólnego przeznaczenia)|
|JP7|SCL|Pozwala na wykorzystanie interfejsu I2C modułu **RN2483A** poprzez złącze J4 (dotyczy tylko wariantu 3)|
|JP8|SDA|Pozwala na wykorzystanie interfejsu I2C modułu **RN2483A** poprzez złącze J4 (dotyczy tylko wariantu 3)|
|JP5|RX|Pozwala na wykorzystanie portu szeregowego modułu **RN2483A** poprzez złącze J3 (dotyczy tylko wariantu 3)|
|JP6|TX|Pozwala na wykorzystanie portu szeregowego modułu **RN2483A** poprzez złącze J3 (dotyczy tylko wariantu 3)|
|JP1|LED RN|Pozwala na wykorzystanie diody LED z poziomu oprogramowania modułu **RN2483A** (dotyczy tylko wariantu 3)|

# Lista elementów
W kolumnach A, B, C, D i E zaznaczone zostały elementy wymagane (+) i opcjonalne (\*) dla odpowiednich wariantów zasilania urządzenia:
* A - wersja minimalna (tylko Arduino i moduł LoRa/LoRaWAN) - zasilanie zewnętrzne bateryjne (opcjonalnie zasilanie zewnętrzne stabilizowane 3.3V) lub 5V z wykorzystaniem stabilizatora napięcia z Arduino Pro Mini - [instrukcja dla wersji A](doc/A_minimal.md)
* B - zasilanie z portu USB
* C - zasilanie bateriami o napięciu do **3V** (np. baterie alkaliczne lub litowe - guzikowe)
* D - zasilanie bateriami litowymi nieładowalnymi o napięciu **3.6V**
* E - zasilanie akumulatorami Li-Ion oraz Li-Po o napięciu **3.7V**

> **UWAGA!** Wersja minimalna wykorzystuje baterię lub stabilizator napięcia z Arduino Pro Mini (poprzez podłączenie zasilana do pinu RAW zamiast VCC). W takim przypadku należy stosować **tylko Arduino Pro Mini 3.3V** ze względu na dopuszczalne napięcie zasilania modułu RFM95W.

| Nazwa | Element |A|B|C|D|E| Sekcja |
|:-----:|:---|-|-|-|-|-|---|
|U5|Arduino Pro Mini|+|+|+|+|+| |
|U1|RFM95W (**dotyczy tylko wersji z RFM95W**)|+|+|+|+|+|LoRa|
|U4|RN2483A (**dotyczy tylko wersji z RN2483A**)|+|+|+|+|+|LoRa|
|R11|51R SMD 1206 (**dotyczy tylko wersji z RN2483A**)|+|+|+|+|+|LoRa|
|R12|10k SMD 1206 (**dotyczy tylko wersji z RN2483A**)|+|+|+|+|+|LoRa|
|J2|U.FL gniazdo antenowe|\*|\*|\*|\*|\*|LoRa|
|U2|TS2940-3.3 SOT-223 regulator napięcia LDO| |+| |+|+|Zasilanie|
|C2|100nF MLCC 1206| |+| |+|+|Zasilanie|
|C3|22uF 6,3V Tantalum CASE:A| |+| |+|+|Zasilanie|
|SW1|Switch 1P2T os102011ma1qn1 (włącznik zasilania)| |\*|\*|\*|\*|Zasilanie|
|J1|Wurth Elektronik 629105136821 Micro Usb| |+| | |+|Zasilanie i Ładowarka|
|bateria AA|KEYSTONE 2915 (**wymagne dwie sztuki na płytkę**)| | | |\*|\*|Zasilanie i Ładowarka|
|BAT|JST-PH 2pin 2mm| | |+|\*|\*|Zasilanie i Ładowarka|
|U3|MCP73831-2-OT kontroler ładowania| | | | |+|Ładowarka|
|C1|4,7μF MLCC 1206| | | | |+|Ładowarka|
|C4|4,7μF MLCC 1206| | | | |+|Ładowarka|
|R1|4k SMD 1206| | | | |+|Ładowarka|
|SOLAR|JST-PH 2pin 2mm| | | | |\*|Ładowarka|
|R6|33k SMD 1206| | |+|+|+|Pomiar napięcia baterii|
|R5|100k SMD 1206| | |+|+|+|Pomiar napięcia baterii|
|D1|LED SMD 1206 (LED)| |\*|\*|\*|\*|Diody LED|
|D2|LED SMD 1206 (VCC)| |+|+|+|+|Diody LED|
|D3|LED SMD 1206 (CHR)| | | | |+|Diody LED|
|R8|1k SMD 1206| |+|+|+|+|Diody LED|
|R9|1k SMD 1206| |\*|\*|\*|\*|Diody LED|
|R10|470R SMD 1206| | | | |+|Diody LED|
|J3|WR-PHD 2.54 mm SMT Pin Header 61000418221 (UART)| |\*|\*|\*|\*|Interfejsy komunikacyjne|
|J4|WR-PHD 2.54 mm SMT Dual Pin Header 61000821121 (I2C)| |\*|\*|\*|\*|Interfejsy komunikacyjne|
|R2|10k SMD 1206| |\*|\*|\*|\*|Interfejsy komunikacyjne|
|R3|10k SMD 1206| |\*|\*|\*|\*|Interfejsy komunikacyjne|
|Q1|BC817 SOT-23 Tranzystor NPN| |\*| |\*|\*|Zasilanie układów zew.|
|Q2|YJL2301F SOT-23 Tranzystor MOSFET| |\*| |\*|\*|Zasilanie układów zew.|
|R7|10k SMD 1206| |\*| |\*|\*|Zasilanie układów zew.|
|R4|1k SMD 1206| |\*| |\*|\*|Zasilanie układów zew.|

# Uwagi
W schemacie została wprowadzona zmiana elementu **Q2** na **YJL2301F**. Zmienił się również sposób jego podłączenia. 

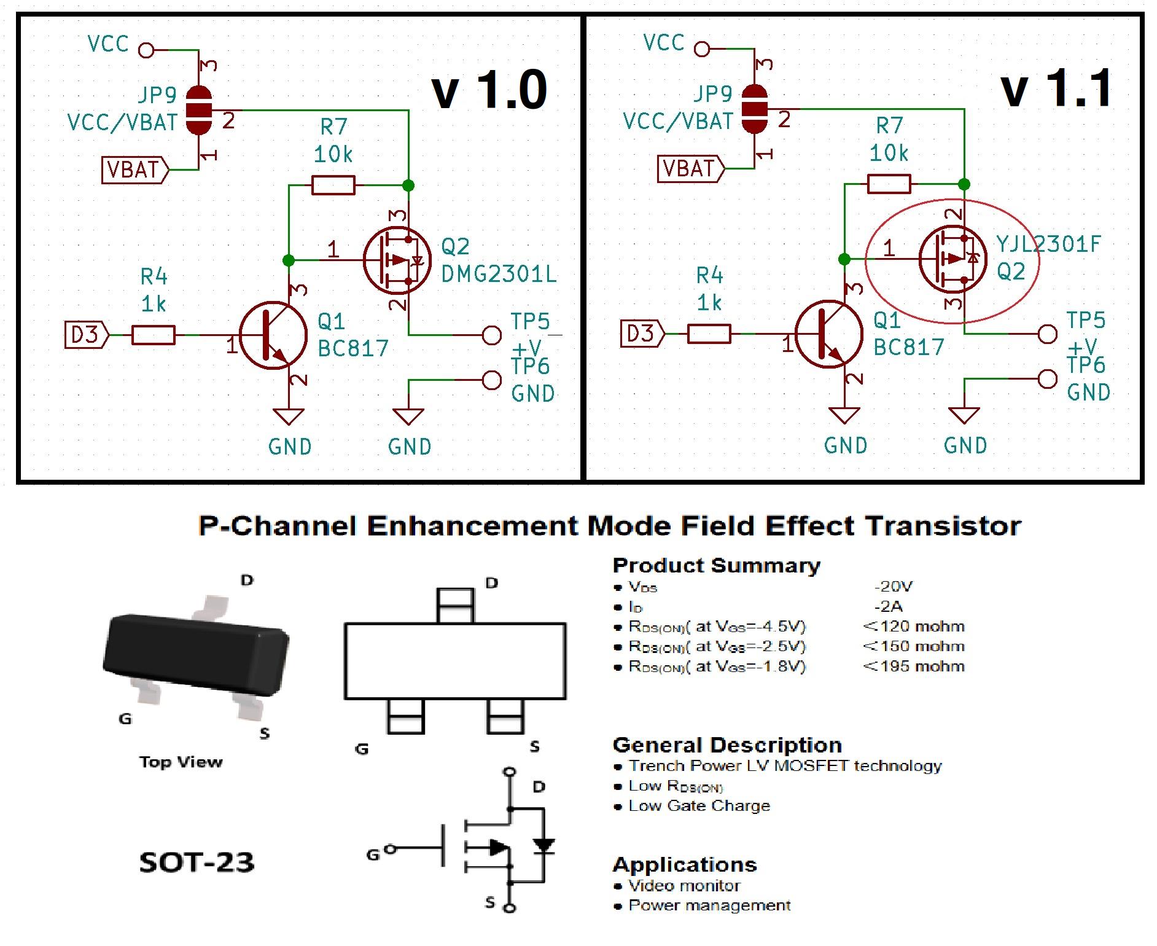
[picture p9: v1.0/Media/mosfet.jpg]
mosfet update


> **UWAGA! Opisana poniżej modyfikacja dotyczy tylko płytki w wersji 1.0.**

Należy uwzględnić poprawkę w montażu płytki - tranzystor Q2 musi być odwrócony "do góry nóżkami" i wlutowany w następujący sposób:

mosfet pcb

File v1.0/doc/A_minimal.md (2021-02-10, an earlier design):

# Wersja minimalna urządzenia

Wersja minimalna urządzenia jest najłatwiejsza do zbudowania dla początkującego użytkownika. 
Wymaga zastosowania baterii (wariant A1) lub zewnętrznego zasilacza USB (wariant A2) podłączonych bezpośrednio do Arduino. W przypadku podłączenia zasilania bezpośrednio do Arduino można pominąć montaż na płytce dodatkowych komponentów SMD.

> *Do zbudowania wersji minimalnej można użyć płytki w wersji 1.0 lub 1.1*

## Wymagane elementy

| Nr| Wariant | Element | Ilość | Uwagi |
|---|---|---|---|---|
|1| |Moduł micro USB|1| Umożliwia zastosowanie standardowego zasilacza USB 5V|
|2| |Konwerter USB-UART|1| Konieczny do wgrania oprogramowania do Arduino|
|3| |RFM95W|1| Moduł nadawczo-odbiorczy LoRa 868 MHz|
|4| |Arduino Pro Mini|1| Wersja 3.3V|
|5|A1|Zasilacz USB 5V|1| Możliwe zastosowanie zasilacza 16V|
|6|A2|Bateria|1|Bateria od 2.7V do 3.7V (np. dwie baterie AA)|

## Lista czynności

1. Zamówienie PCB
2. Podłączenie Arduino Pro Mini
3. Podłączenie RFM95W i anteny
4. Rejestracja urządzenia w sieci LoRaWAN The Things Network
5. Kompilacja programu
6. Wgrywanie programu
7. Podłączenie zasilania i uruchomienie

### Zamówienie PCB

Dla wersji minimalnej urządzenia możemy użyć płytki w wersji 1.0, jak i 1.1. Archiwum z plikami Gerber wymagane przy składaniu zamówienia: [Pliki_produkcyjne.zip](/v1.1/Pliki_produkcyjne.zip)

### Podłączenie Arduino Pro Mini

Wykorzystane gniazda i listwy typu goldpin

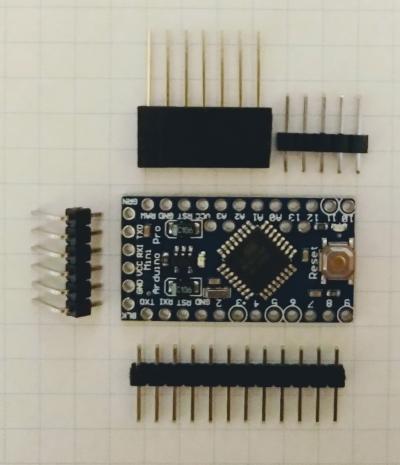
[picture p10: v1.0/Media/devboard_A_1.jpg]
Gniazda


Arduino z wlutowanymi goldpinami

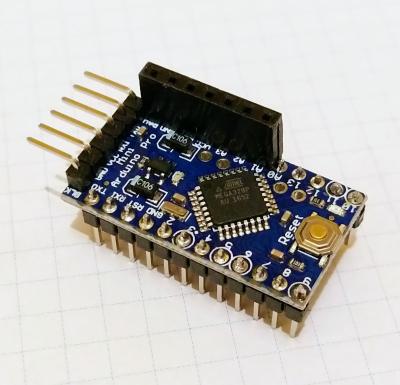
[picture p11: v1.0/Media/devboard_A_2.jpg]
Arduino


### Podłączenie RFM95W i anteny

Płytka z przylutowanym modułem RFM95 i anteną helikalną. Antena wykonana zgodnie z opisem zamieszczonym na blogu http://e.pavlin.si/2018/06/29/small-normal-mode-antenna-for-868mhz/ (powyżej płytki przewód do płytki stykowej wykorzystany do zrobienia anteny). Zamiast anteny helikalnej można przylutować prosty przewód lub drucik długości 8,7cm.

>**Uwaga!** Po przylutowaniu RFM95W nie podłączamy zasialania zanim nie przylutujemy anteny. **Podłączenie zasilania bez anteny może uszkodzić RFM95W**

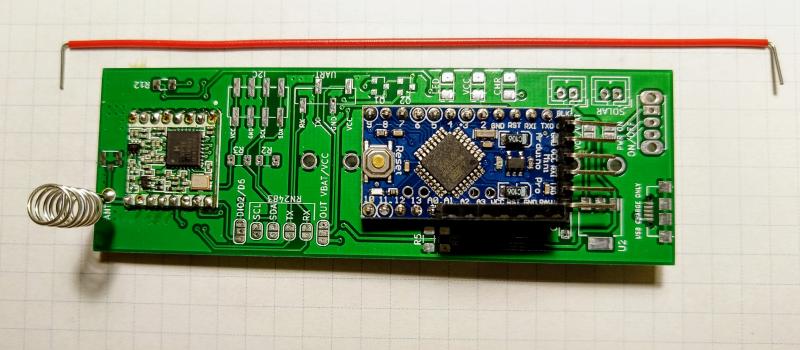
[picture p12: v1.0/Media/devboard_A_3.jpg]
RFM95 i antena


### Rejestracja urządzenia w sieci LoRaWAN The Things Network

Przed przystąpieniem do kompilowania przykładowego programu i wgraniem go do urządzenia, musimy to urządznie zarejestrować u wybranego dostawcy sieci LoRaWAN - w tym przypadku The Things Network.

Proces rejestracji jest dobrze opisany w [dokumentacji The Things Network](https://www.thethingsnetwork.org/docs/devices/registration.html) - pamiętajmy o wybraniu metody aktywacji ABP. 

### Kompilacja programu

Do skompilowania i wgrania programu można zastosowac Arduino IDE. Należy pamiętać o:

* zainstalowaniu wymaganych przez program bibliotek - wymienione w [/templates/README.md](/templates/README.md)
* wybraniu z menu właściwego rodzaju płytki - Arduino Pro Mini
* wybraniu z menu własciwego procesora - 3.3V, 8MHz

Najprościej będzie utworzyć nowy sketch (menu: `Plik > Nowy`), wykasować cały domyślny kod, który się pojawia, wkleić zawartość naszego szablonu `lorawan-rfm-template.ino` i zapisać plik pod wybraną nazwą.

Następnie możemy dokonać niezbędnych modyfikacji kodu, zaczynając od parametrów konfiguracyjnych urządzenia.

Przypisane urządzeniu w trakcie rejestracji wartości `Device Address`, `Network Session Key`, oraz `App Session Key` należy wpisać do kodu szablonu poniżej linii `// ABP mode - set DevAddr and session keys`:

|Nazwa w Device Settings|Nazwa zmiennej w szablonie|
|---|---|
|Device Address|DEVADDR|
|Network Session Key|NWKSKEY|
|App Session Key|APPSKEY|

Fragment programu z podstawionymi parametrami:

```
//...

// ------- LoRaWAN configuration

// ABP mode - set DevAddr and session keys
static const PROGMEM u1_t NWKSKEY[16] = { 0x11, 0x09, 0xAD, 0x04, 0x4C, 0x4F, 0xB7, 0xA5, 0x2D, 0x86, 0xF7, 0x2E, 0xD0, 0xDD, 0x5B, 0x3B };
static const PROGMEM u1_t APPSKEY[16] = { 0xE0, 0xD8, 0x4F, 0xEE, 0xC3, 0x7C, 0xC9, 0x9B, 0xD3, 0xF2, 0x03, 0x61, 0xE4, 0xF2, 0x5B, 0xFE };
static const u4_t DEVADDR = 0x2601108E;

// ...
```

### Wgrywanie programu (szkicu)

Do wgrania skompilowanego programu na Arduino konieczne będzie podłączenie go z wykorzystaniem konwertera USB-UART.

Sposób połączenia pinów konwertera z pinami Arduino pokazany w tabeli poniżej (w nawiasach alternatywne oznaczenia, które można spotkać na niektórych konwerterach). Nie należy sugerować się na kolejnością w tabeli, tylko sprawdzić napisy na płytkach - nowsze wersje Arduino Pro Mini mają odwrotną kolejność pinów niż starsze.

|Adruino Pro Mini|FT232|
|---|---|
|BLK|GND|
|GND|CTS (CTS#)|
|VCC|VCC|
|RXI|TXD|
|TXD|RXD|
|GNR|DTR (RTX#)|

>**Uwaga! Należy pamiętać o odpowiednim ustawienie na FT232 zworki 3.3v/5V  w pozycji 3.3V - zgodnie z używaną w tym przykładzie wersją Arduino**

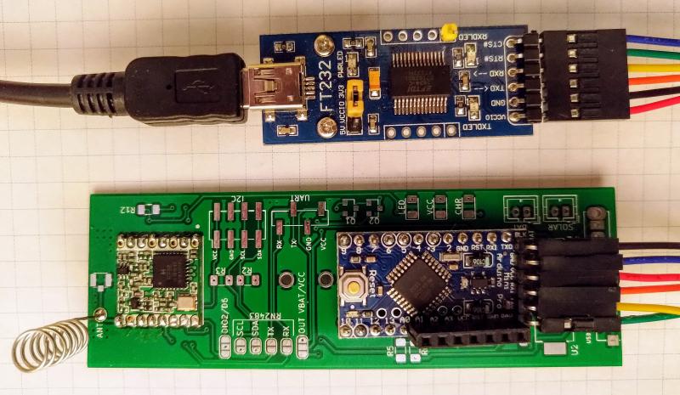
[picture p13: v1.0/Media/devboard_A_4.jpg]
Podłączenie konwertera


Z menu Arduino IDE wybieramy opcję `Szkic > Wgraj` i czekamy na wyświetlenie się komunikatu o zakończeniu procesu wgrywania programu do Arduino.

### Podłączenie zasilania i uruchomienie

Jeśli kompilacja i wgranie programu zakończyło się bez błedu, możemy odłączyć konwerter USB-UART od Arduino.

#### Wariant  A1 z zasilaczem USB 5V
Podłaczamy zasilacz USB 5V, korzystając z Modułu Micro USB połączonego z pinami Arduino jak na ilustracji poniżej. Przewody z modułu USB wpinamy w gniazda RAW (5V) oraz GND Arduino.

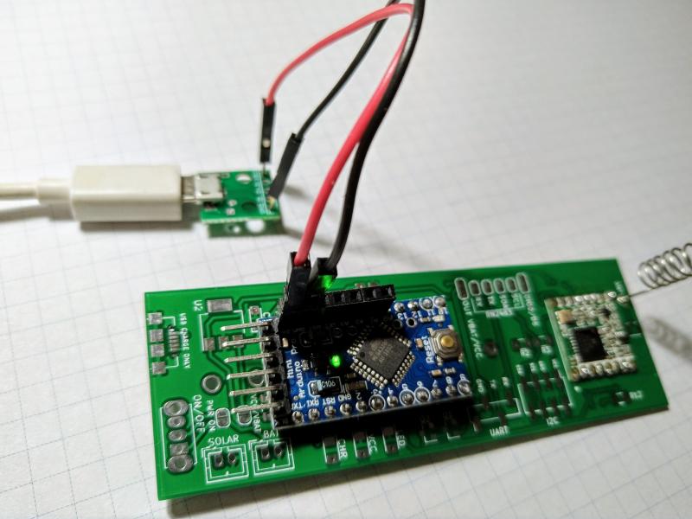
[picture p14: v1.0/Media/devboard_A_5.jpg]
Podłączenie zasilacza USB


#### Wariant A2 z baterią

Baterię podłączmy do gniazd VCC oraz GND Arduino

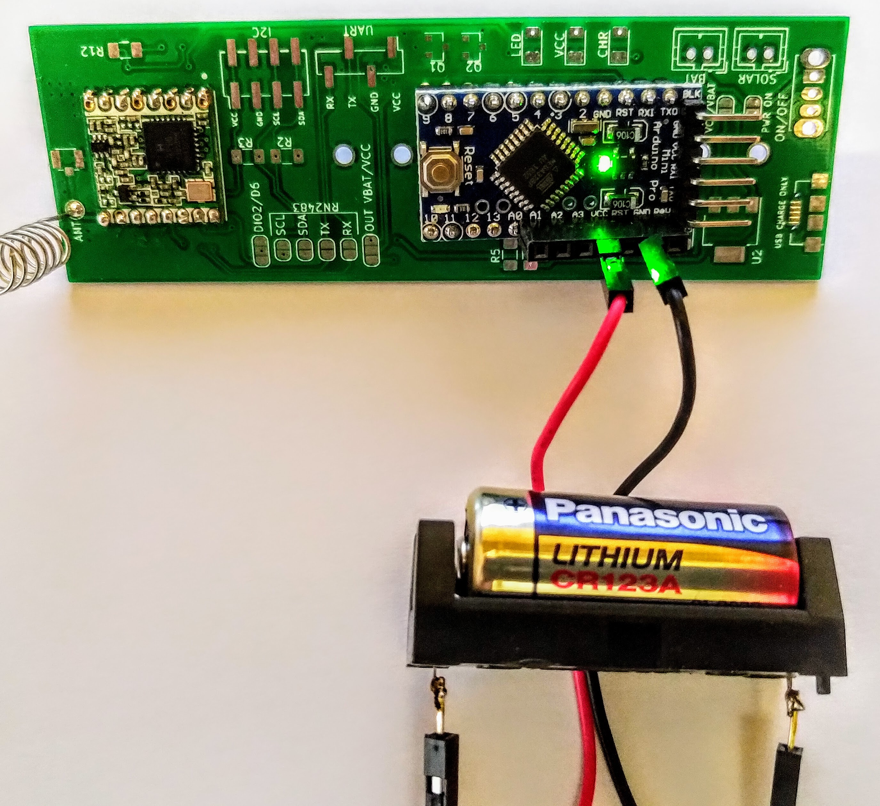
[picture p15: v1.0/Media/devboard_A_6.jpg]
Podsystem baterii


#### Zmniejszenie poboru prądu

W przypadku zasilania bateryjnego warto rozważyć możliwość zmniejszenia poboru prądu przez Arduino oraz RFM95W. W tym celu należy:

* wprowdzić Arduino oraz RFM95W w tryb uśpienia - z poziomu kodu aplikacji poprzez użycie biblioteki LowPower https://github.com/rocketscream/Low-Power 
* fizycznie odłączyć podsystem zasilania Arduino poprzez odlutowanie regulatora MIC5205 i diody LED1 lub usunięcie kropli cyny ze zworki SJ1 (jeśli mamy oryginalną wersję Arduino).
Ważniejsze jest usunięcie LED1, bo MIC2505 pobiera w w trybie uśpienia jedynie dodatkowe 4 &micro;A

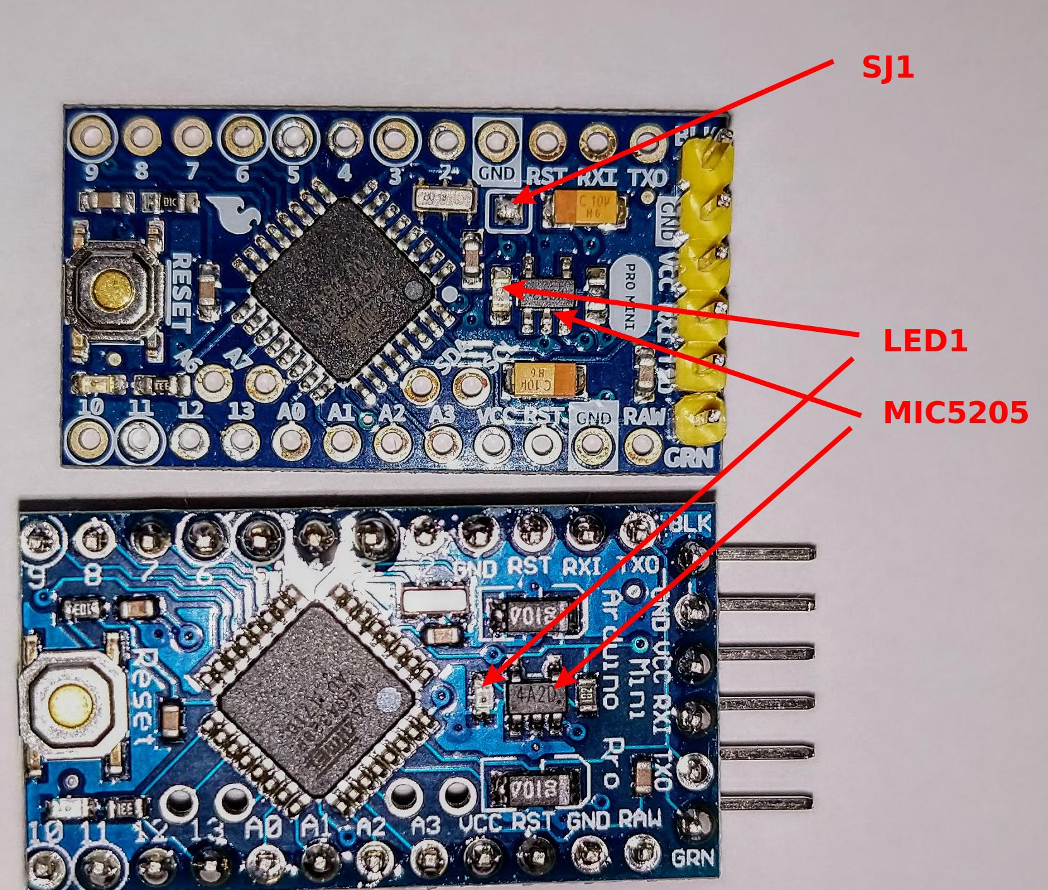
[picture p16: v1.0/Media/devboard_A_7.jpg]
Podsystem zasilania


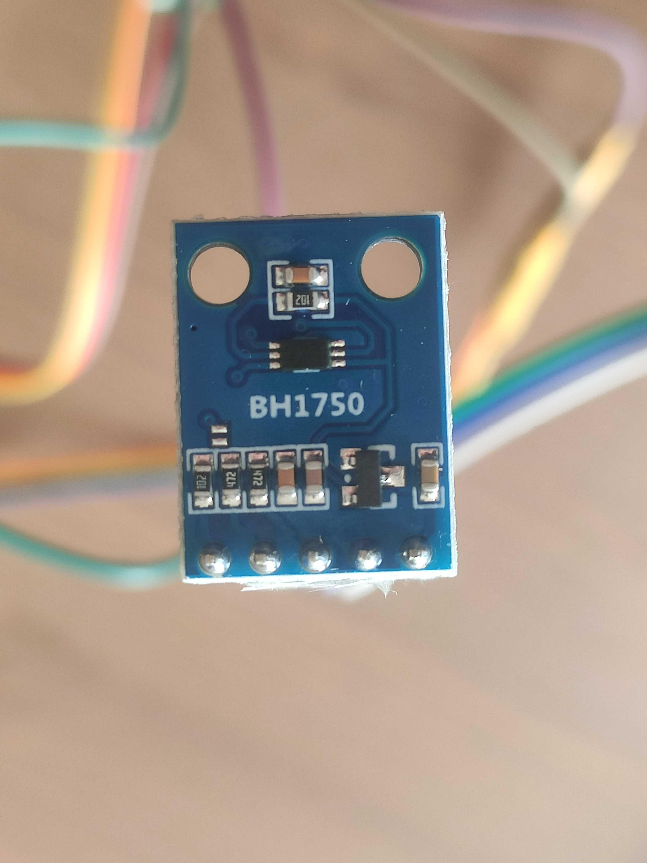
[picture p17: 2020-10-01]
projects/smogometr-dev-board-rfm95w/media/BH1750.jpg

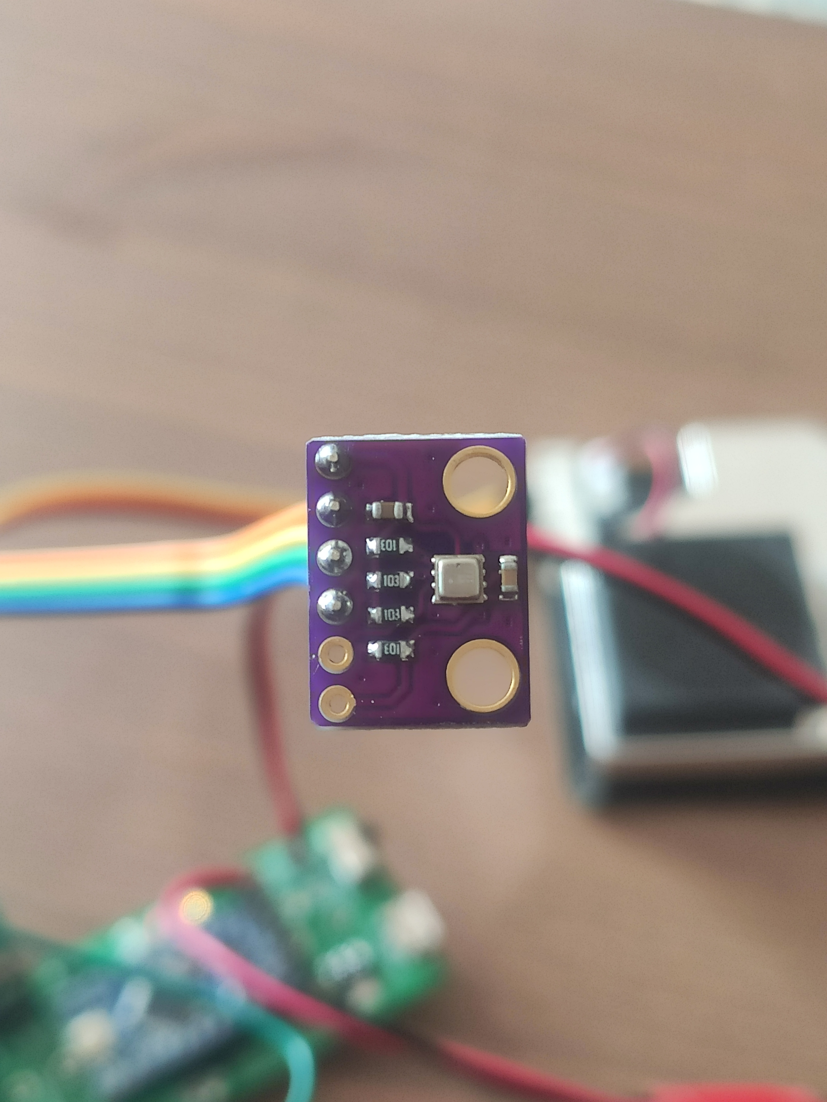
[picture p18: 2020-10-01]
projects/smogometr-dev-board-rfm95w/media/BME280.jpg

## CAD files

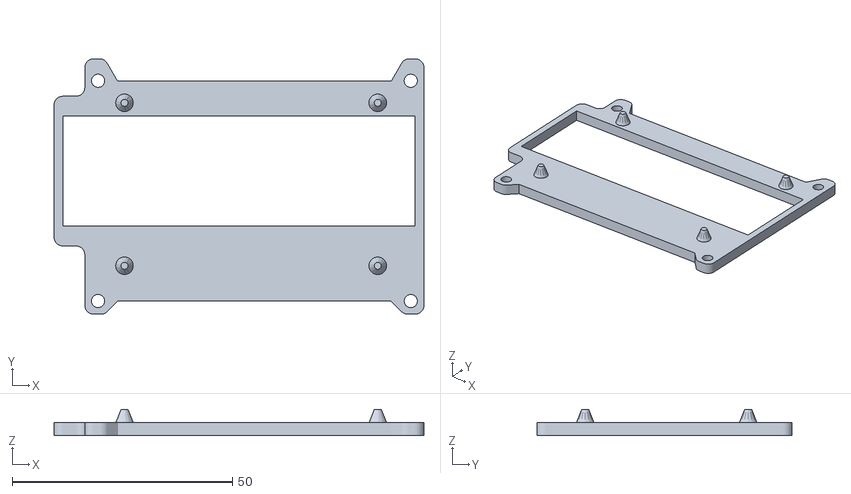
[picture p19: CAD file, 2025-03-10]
projects/weather-station/Obudowa/Podstawa.stl
84.0 x 58.0 x 6.00

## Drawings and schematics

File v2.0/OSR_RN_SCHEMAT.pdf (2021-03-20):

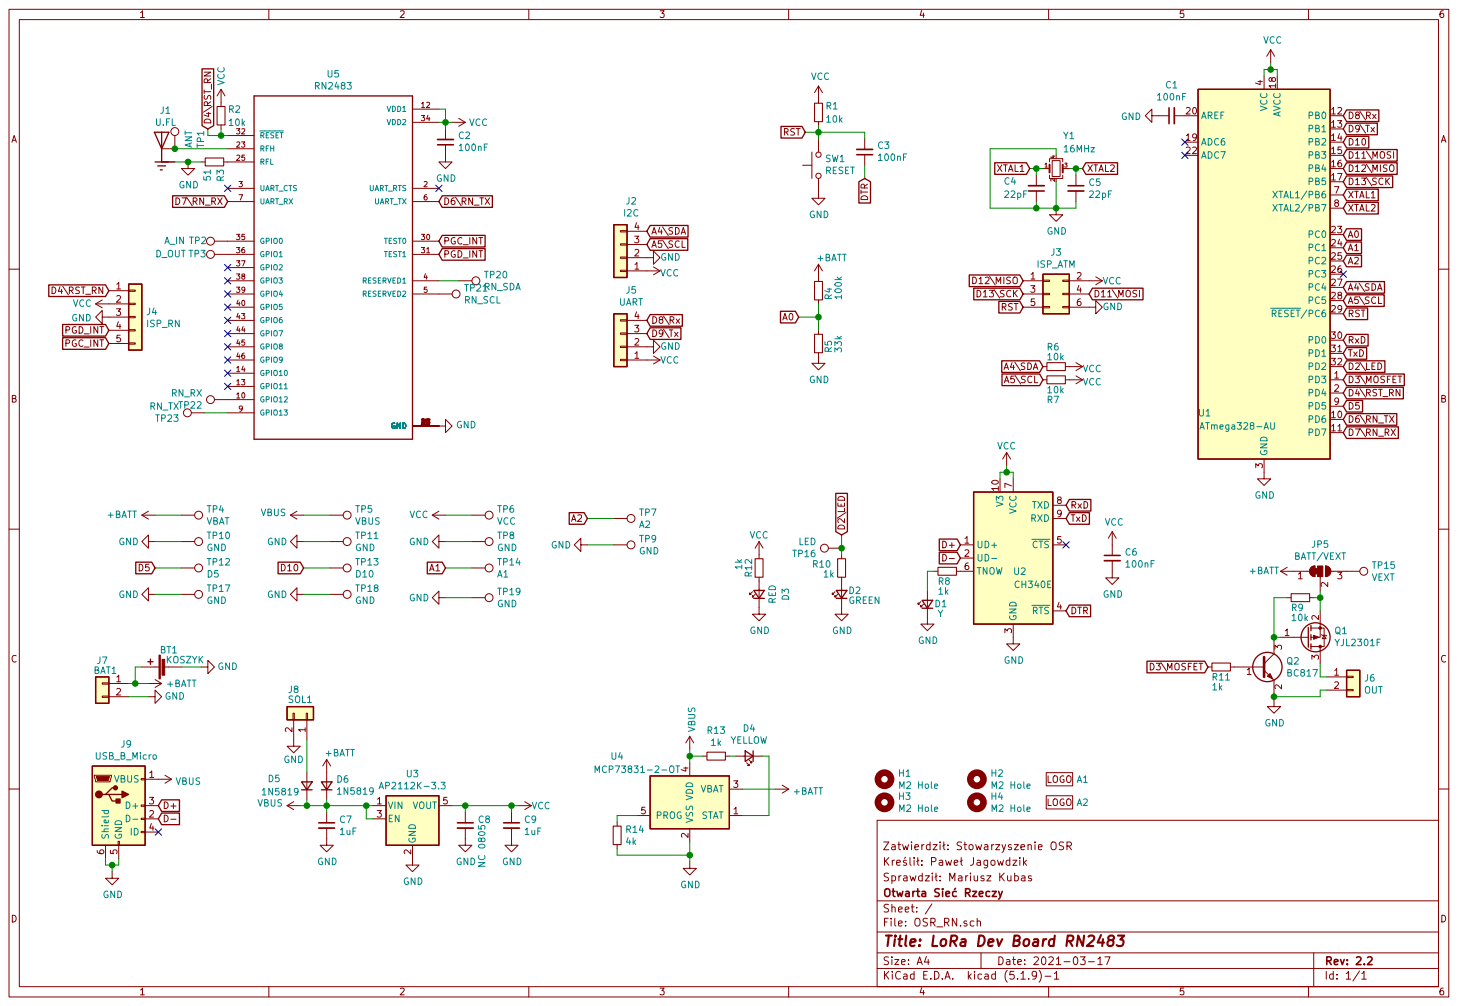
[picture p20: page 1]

3 RTS 4 CTS 5 TNOW 6 VCC

4 PROG 5 U4 MCP73831-2-OT VBUS GND GND

Zatwierdzi: Stowarzyszenie OSR
Kreli: Pawe Jagowdzik
Sprawdzi: Mariusz Kubas
File: OSR_RN.sch Sheet: / Otwarta Sie Rzeczy

Id: 1/1 Title: LoRa Dev Board RN2483

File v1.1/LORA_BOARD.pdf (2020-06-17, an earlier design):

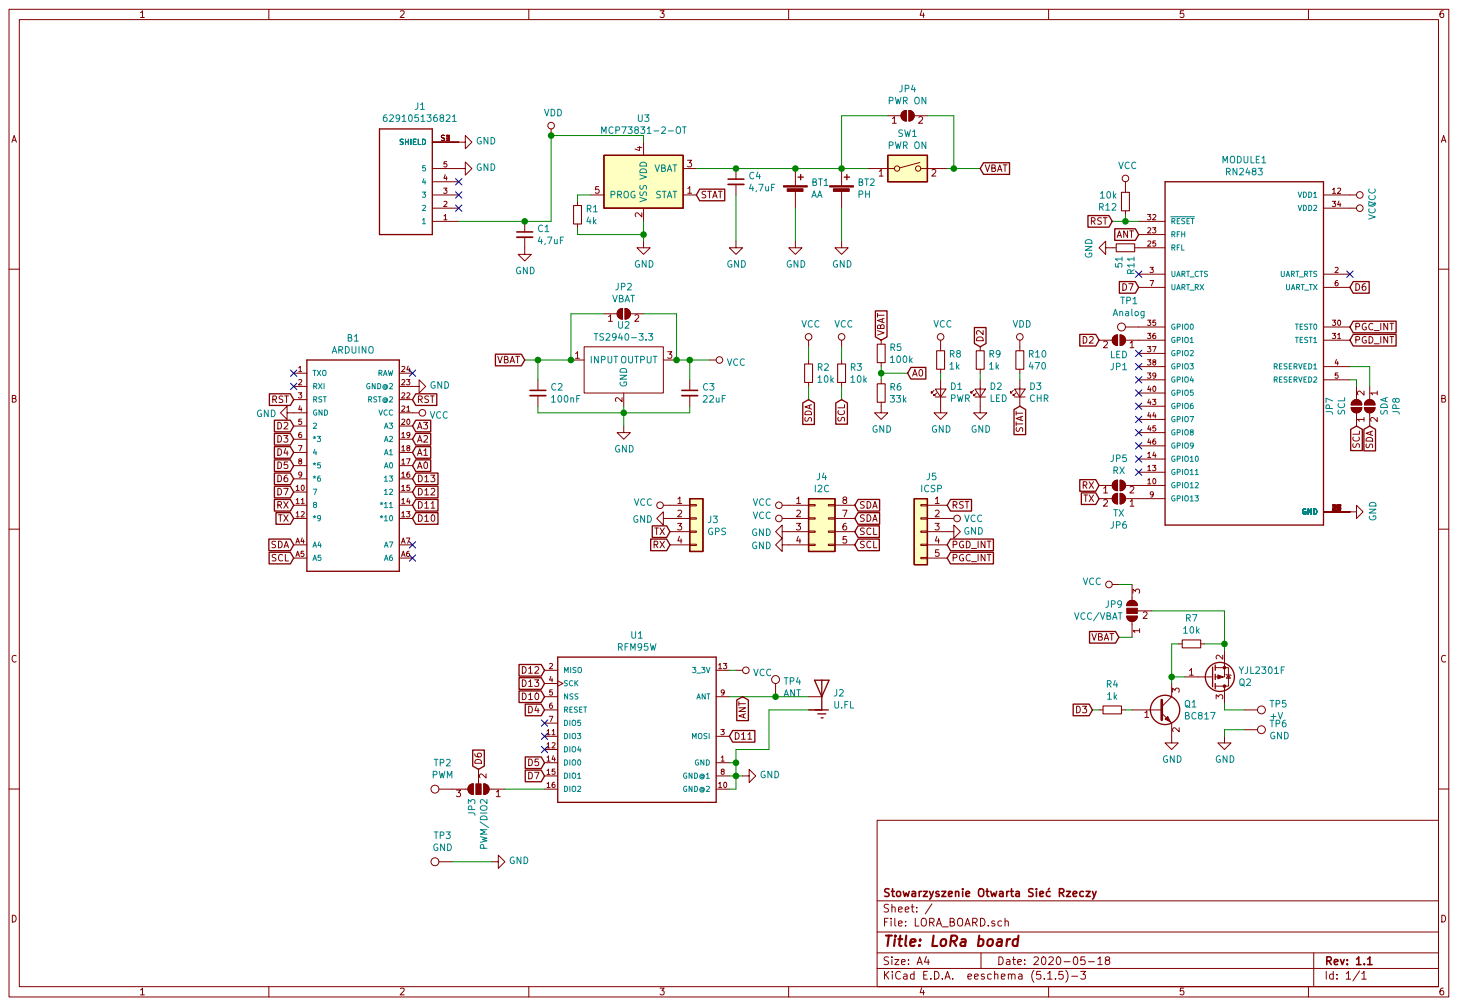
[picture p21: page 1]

File: LORA_BOARD.sch Sheet: / Stowarzyszenie Otwarta Sie Rzeczy

Id: 1/1 Title: LoRa board

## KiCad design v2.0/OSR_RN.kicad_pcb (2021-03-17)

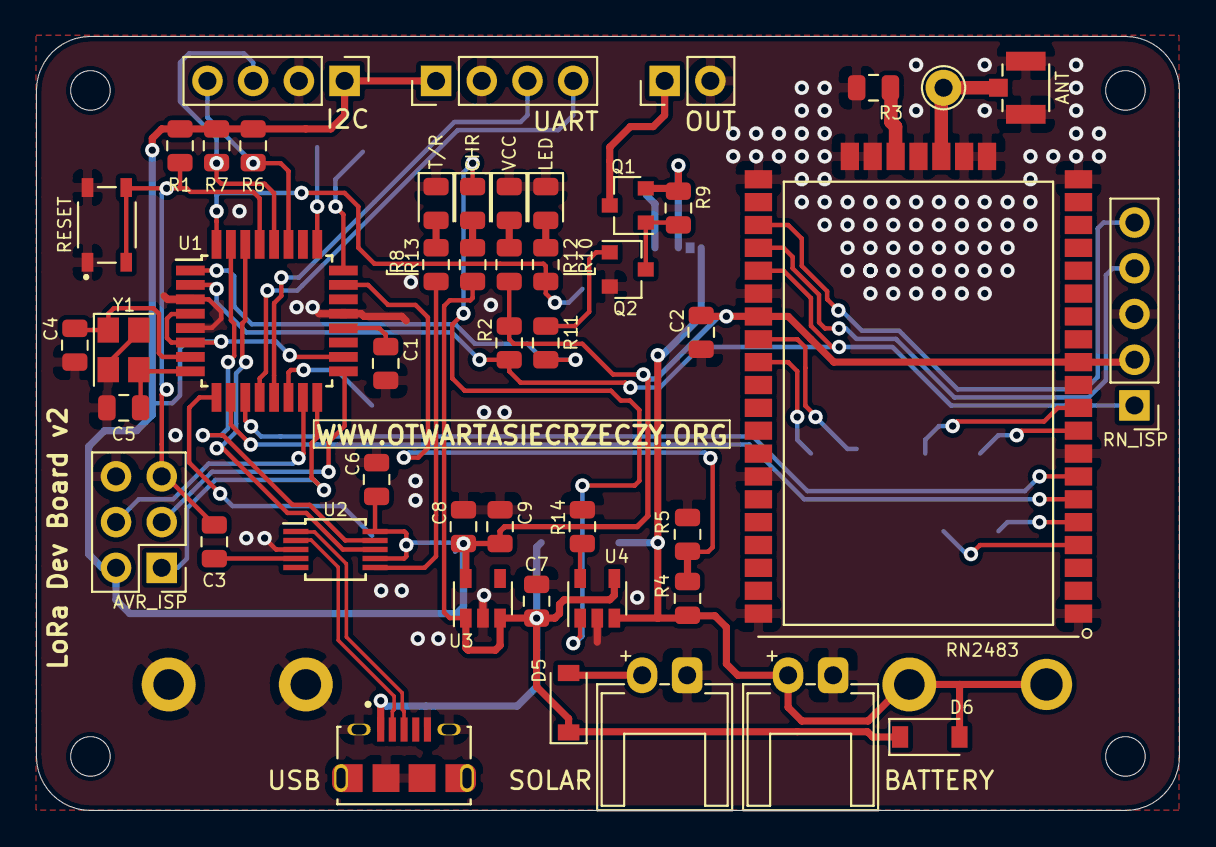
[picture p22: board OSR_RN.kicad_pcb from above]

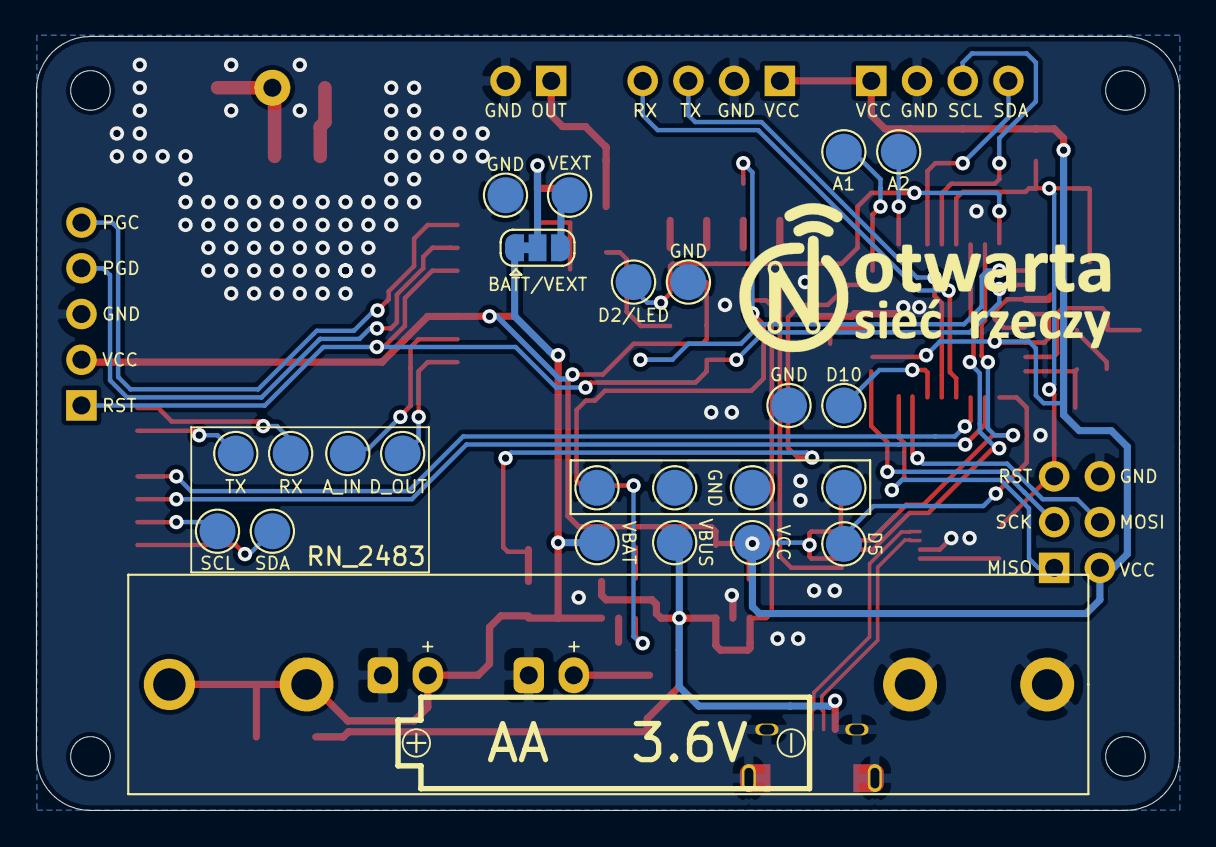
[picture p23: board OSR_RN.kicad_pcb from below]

Board: 2 copper layers, 63.5 x 43.0 mm, 76 parts (24 on the bottom side), 53 nets.

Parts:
A1: A1; TestPoint_Pad_D2.0mm
A2: A2; TestPoint_Pad_D2.0mm
ANT: U.FL; HRS_U.FL-R-SMT-1(10)
AVR_ISP: ISP_ATM; PinHeader_2x03_P2.54mm_Vertical
A_IN: A_IN; TestPoint_Pad_D2.0mm
BATTERY: BAT1; XH-2AW
BT1: KOSZYK; 2915_keystone
C1, C2, C3, C6: 100nF; C_0805_2012Metric
C4, C5: 22pF; C_0805_2012Metric
C7, C9: 1uF; C_0805_2012Metric
C8: NC 0805; C_0805_2012Metric
CHR: YELLOW; LED_0805_2012Metric
D2/LED: LED; TestPoint_Pad_D2.0mm
D5: D5; TestPoint_Pad_D2.0mm
D5#2, D6: 1N5819; D_SOD-123
D10: D10; TestPoint_Pad_D2.0mm
D_OUT: D_OUT; TestPoint_Pad_D2.0mm
GND: GND; TestPoint_Pad_D2.0mm
GND#2, GND#3, GND#4: GND; TestPoint_Pad_D2.0mm
H1, H2, H3, H4: M2 Hole; MountingHole_2.2mm_M2_DIN965
I2C: I2C; PinHeader_1x04_P2.54mm_Vertical
JP5: BATT/VEXT; SolderJumper-3_P1.3mm_Bridged12_RoundedPad1.0x1.5mm
LED: GREEN; LED_0805_2012Metric
OUT: OUT; PinHeader_1x02_P2.54mm_Vertical
Q1: YJL2301F; SOT-23
Q2: BC817; SOT-23
R1, R2, R6, R7, R9: 10k; R_0805_2012Metric
R3: 51; R_0805_2012Metric
R4: 100k; R_0805_2012Metric
R5: 33k; R_0805_2012Metric
R8, R10, R11, R12, R13: 1k; R_0805_2012Metric
R14: 4k; R_0805_2012Metric
RESET: RESET; SW_SKRPACE010
RN2483: RN2483; RM095
RN_ISP: ISP_RN; PinHeader_1x05_P2.54mm_Vertical
RX: RN_RX; TestPoint_Pad_D2.0mm
SCL: RN_SCL; TestPoint_Pad_D2.0mm
SDA: RN_SDA; TestPoint_Pad_D2.0mm
SOLAR: SOL1; XH-2AW
T/R: Y; LED_0805_2012Metric
TP1: ANT; TestPoint_THTPad_D2.0mm_Drill1.0mm
TP9, TP10, TP11: GND; TestPoint_Pad_D2.0mm
TX: RN_TX; TestPoint_Pad_D2.0mm
U1: ATmega328-AU; TQFP-32_7x7mm_P0.8mm
U2: CH340E; MSOP-10_3x3mm_P0.5mm
U3: AP2112K-3.3; SOT-23-5
U4: MCP73831-2-OT; SOT-23-5
UART: UART; PinHeader_1x04_P2.54mm_Vertical
USB: USB_B_Micro; AMPHENOL_10118194-0001LF
VBAT: VBAT; TestPoint_Pad_D2.0mm
VBUS: VBUS; TestPoint_Pad_D2.0mm
VCC: RED; LED_0805_2012Metric
VCC#2: VCC; TestPoint_Pad_D2.0mm
VEXT: VEXT; TestPoint_Pad_D2.0mm
Y1: 16MHz; Crystal_SMD_3225-4Pin_3.2x2.5mm

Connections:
+BATT: BATTERY.1, BT1.1, D6.2, JP5.1, R4.1, U4.3, VBAT.1
A0: R4.2, R5.1, U1.23
A1: A1.1, U1.24
A2: A2.1, U1.25
A4\SDA: I2C.4, R6.2, U1.27
A5\SCL: I2C.3, R7.2, U1.28
D2\LED: D2/LED.1, R10.2, U1.32
D3\MOSFET: R11.2, U1.1
D4\RST_RN: R2.2, RN2483.32, RN_ISP.1, U1.2
D5: D5.1, U1.9
D6\RN_TX: RN2483.6, U1.10
D7\RN_RX: RN2483.7, U1.11
D8\Rx: U1.12, UART.4
D9\Tx: U1.13, UART.3
D10: D10.1, U1.14
D11\MOSI: AVR_ISP.4, U1.15
D12\MISO: AVR_ISP.1, U1.16
D13\SCK: AVR_ISP.3, U1.17
D+: U2.1, USB.3
D-: U2.2, USB.2
DTR: C3.1, U2.4
GND: ANT.1, ANT.3, AVR_ISP.6, BATTERY.2, BT1.2, C1.1, C2.1, C4.1, C5.2, C6.2, C7.2, C8.2, C9.2, GND.1, GND#2.1, GND#3.1, GND#4.1, I2C.2, LED.1, OUT.2, Q2.2, R3.2, R5.2, R14.2, RESET.1, RN2483.1, RN2483.8, RN2483.11, RN2483.20, RN2483.21, RN2483.22, RN2483.24, RN2483.26, RN2483.27, RN2483.28, RN2483.33, RN2483.41, RN2483.47, RN_ISP.3, SOLAR.2, T/R.1, TP9.1, TP10.1, TP11.1, U1.3, U1.5, U1.21, U2.3, U3.2, U4.2, UART.2, USB.5, USB.6, VCC.1, Y1.2, Y1.4
unnamed: C1.2, U1.20
unnamed: R8.2, T/R.2
unnamed: LED.2, R10.1
unnamed: R12.1, VCC.2
unnamed: CHR.1, U4.1
unnamed: CHR.2, R13.1
unnamed: D5#2.2, SOLAR.1
unnamed: ANT.2, RN2483.23, TP1.1
unnamed: OUT.1, Q1.3
unnamed: JP5.2, Q1.2, R9.1
unnamed: JP5.3, VEXT.1
unnamed: Q1.1, Q2.3, R9.2
unnamed: Q2.1, R11.1
unnamed: R3.1, RN2483.25
unnamed: R8.1, U2.6
unnamed: R14.1, U4.5
unnamed: A_IN.1, RN2483.35
unnamed: D_OUT.1, RN2483.36
unnamed: RN2483.4, SDA.1
unnamed: RN2483.5, SCL.1
unnamed: RN2483.10, RX.1
unnamed: RN2483.9, TX.1
PGC_INT: RN2483.30, RN_ISP.5
PGD_INT: RN2483.31, RN_ISP.4
RST: AVR_ISP.5, C3.2, R1.2, RESET.2, U1.29
RxD: U1.30, U2.8
TxD: U1.31, U2.9
VBUS: C7.1, D5#2.1, D6.1, R13.2, U3.1, U3.3, U4.4, USB.1, VBUS.1
VCC: AVR_ISP.2, C2.2, C6.1, C8.1, C9.1, I2C.1, R1.1, R2.1, R6.1, R7.1, R12.2, RN2483.12, RN2483.34, RN_ISP.2, U1.4, U1.6, U1.18, U2.7, U2.10, U3.5, UART.1, VCC#2.1
XTAL1: C4.2, U1.7, Y1.1
XTAL2: C5.1, U1.8, Y1.3

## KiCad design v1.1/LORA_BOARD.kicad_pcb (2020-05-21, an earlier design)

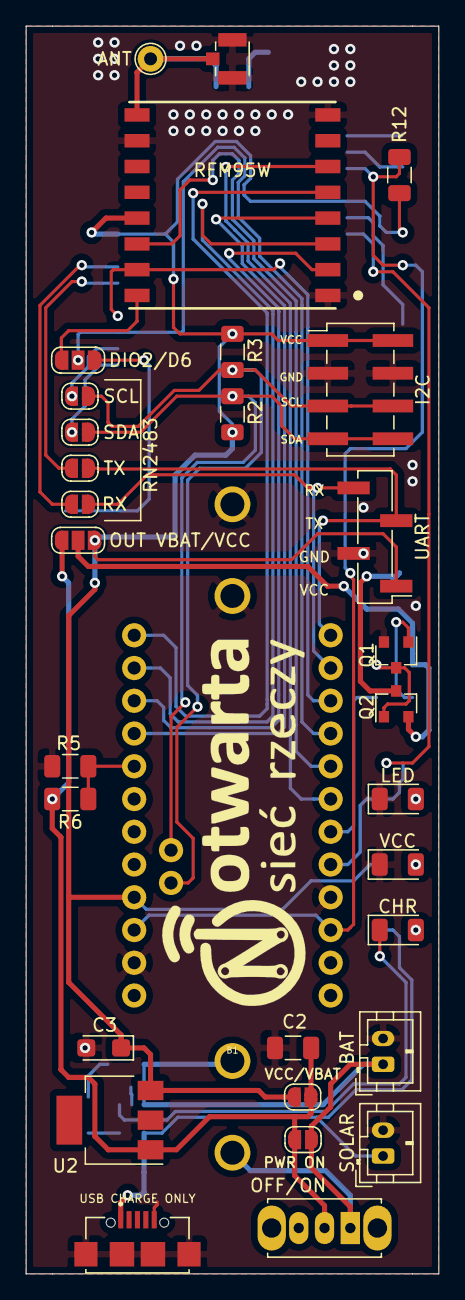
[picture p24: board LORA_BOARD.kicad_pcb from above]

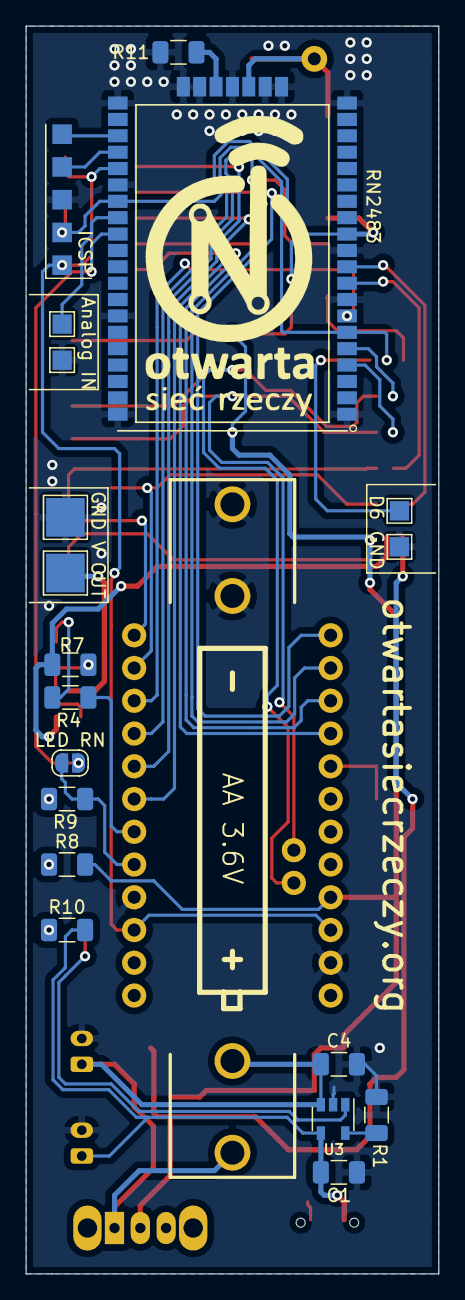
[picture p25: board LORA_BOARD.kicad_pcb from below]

Board: 2 copper layers, 32.0 x 96.8 mm, 53 parts (20 on the bottom side), 42 nets.

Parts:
ANT: ANT; TestPoint_THTPad_D2.0mm_Drill1.0mm
B1: ARDUINO; ARDUINO_PRO_MINI
BAT: PH; JST_PH_B2B-PH-K_1x02_P2.00mm_Vertical
BT1: AA 3.6V; BATTERY-AA-KIT
C1, C4: 4,7uF; C_1206_3216Metric
C2: 100nF; C_1206_3216Metric
C3: 22uF; CP_EIA-3216-18_Kemet-A
CHR: CHR; LED_1206_3216Metric
D6: PWM; TestPoint_Pad_1.5x1.5mm
DIO2/D6: PWM/DIO2; SolderJumper-3_P1.3mm_Open_RoundedPad1.0x1.5mm
GND: GND; TestPoint_Pad_1.5x1.5mm
GND#2: GND; TestPoint_Pad_3.0x3.0mm
GND#3: GND; TestPoint_Pad_1.5x1.5mm
J2: U.FL; HRS_U.FL-R-SMT-1(10)
J3: UART; PinHeader_1x04_P2.54mm_Vertical_SMD_Pin1Left
J4: I2C; PinHeader_2x04_P2.54mm_Vertical_SMD
J5: ICSP; CON_SMD_01x05
LED: LED; LED_1206_3216Metric
LED RN: LED; SolderJumper-2_P1.3mm_Open_RoundedPad1.0x1.5mm
OFF/ON: PWR ON; SW_Slide_1P2T_CK_OS102011MS2Q
OUT VBAT/VCC: VCC/VBAT; SolderJumper-3_P1.3mm_Open_RoundedPad1.0x1.5mm
PWR ON: PWR ON; SolderJumper-2_P1.3mm_Open_RoundedPad1.0x1.5mm
Q1: BC817; SOT-23
Q2: DMG2301L; SOT-23
R1: 4k; R_1206_3216Metric
R2, R3, R7, R12: 10k; R_1206_3216Metric
R4, R8, R9: 1k; R_1206_3216Metric
R5: 100k; R_1206_3216Metric
R6: 33k; R_1206_3216Metric
R10: 470; R_1206_3216Metric
R11: 51; R_1206_3216Metric
RFM95W: RFM95W; XCVR_RFM95W-868S2
RN2483: RN2483; RM095
RX: RX; SolderJumper-2_P1.3mm_Open_RoundedPad1.0x1.5mm
Ref**: Val**; OSR_Vertical_15x25
Ref**#2: Val**; OSR_Horizontal_12x29
SCL: SCL; SolderJumper-2_P1.3mm_Open_RoundedPad1.0x1.5mm
SDA: SDA; SolderJumper-2_P1.3mm_Open_RoundedPad1.0x1.5mm
SOLAR: PH; JST_PH_B2B-PH-K_1x02_P2.00mm_Vertical
TP1: Analog IN; TestPoint_Pad_1.5x1.5mm
TX: TX; SolderJumper-2_P1.3mm_Open_RoundedPad1.0x1.5mm
U2: TS2940-3.3; SOT-223
U3: MCP73831-2-OT; SOT-23-5
USB CHARGE ONLY: 629105136821; WE_629105136821
V OUT: +V; TestPoint_Pad_3.0x3.0mm
VCC: PWR; LED_1206_3216Metric
VCC/VBAT: VBAT; SolderJumper-2_P1.3mm_Open_RoundedPad1.0x1.5mm

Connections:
A0: B1.17, R5.2, R6.1
ANT: ANT.1, J2.2, RFM95W.9, RN2483.23
D2: B1.5, LED RN.2, R9.1
D3: B1.6, R4.2
D4: B1.7, RFM95W.6
D5: B1.8, RFM95W.14
D6: B1.9, DIO2/D6.2, RN2483.6
D7: B1.10, RFM95W.15, RN2483.7
D10: B1.13, RFM95W.5
D11: B1.14, RFM95W.3
D12: B1.15, RFM95W.2
D13: B1.16, RFM95W.4
GND: B1.4, B1.23, BAT.2, BT1.GND@, C1.2, C2.2, C3.2, C4.2, GND.1, GND#2.1, GND#3.1, J2.1, J2.3, J3.2, J4.3, J4.4, J5.3, LED.1, Q1.2, R1.2, R6.2, R11.2, RFM95W.1, RFM95W.8, RFM95W.10, RN2483.1, RN2483.8, RN2483.11, RN2483.20, RN2483.21, RN2483.22, RN2483.24, RN2483.26, RN2483.27, RN2483.28, RN2483.33, RN2483.41, RN2483.47, SOLAR.2, U2.2, U3.2, USB CHARGE ONLY.5, USB CHARGE ONLY.S1, USB CHARGE ONLY.S2, USB CHARGE ONLY.S3, USB CHARGE ONLY.S4, VCC.1
unnamed: BAT.1, BT1.PWR@, C4.1, OFF/ON.1, PWR ON.1, U3.3
unnamed: R8.2, VCC.2
unnamed: LED.2, R9.2
unnamed: CHR.2, R10.2
unnamed: LED RN.1, RN2483.36
unnamed: DIO2/D6.1, RFM95W.16
unnamed: D6.1, DIO2/D6.3
unnamed: RN2483.10, RX.2
unnamed: RN2483.9, TX.1
unnamed: RN2483.5, SCL.2
unnamed: RN2483.4, SDA.1
unnamed: OUT VBAT/VCC.2, Q2.2, R7.1
unnamed: R11.1, RN2483.25
unnamed: RN2483.35, TP1.1
unnamed: Q1.1, R4.1
unnamed: Q1.3, Q2.1, R7.2
unnamed: Q2.3, V OUT.1
unnamed: R1.1, U3.5
PGC_INT: J5.5, RN2483.30
PGD_INT: J5.4, RN2483.31
RST: B1.3, B1.22, J5.1, R12.1, RN2483.32
RX: B1.11, J3.4, RX.1
SCL: B1.A5, J4.5, J4.6, R3.2, SCL.1
SDA: B1.A4, J4.7, J4.8, R2.2, SDA.2
STAT: CHR.1, U3.1
TX: B1.12, J3.3, TX.2
VBAT: C2.1, OFF/ON.2, OUT VBAT/VCC.1, PWR ON.2, R5.1, U2.1, VCC/VBAT.1
VCC: B1.21, C3.1, J3.1, J4.1, J4.2, J5.2, OUT VBAT/VCC.3, R2.1, R3.1, R8.1, R12.2, RFM95W.13, RN2483.12, RN2483.34, U2.3, VCC/VBAT.2
VDD: C1.1, R10.1, SOLAR.1, U3.4, USB CHARGE ONLY.1

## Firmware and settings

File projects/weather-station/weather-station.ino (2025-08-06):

#include <TheThingsNetwork.h>
#include <SoftwareSerial.h>
#include <CayenneLPP.h>
#include <LowPower.h>
#include <DallasTemperature.h>
#include <OneWire.h>
#include <Adafruit_BME280.h>

#define LOW_POWER

#define USER_LED 2
#define ONE_WIRE_BUS 9

#define VBAT (analogRead(A0) * 0.013) // napięcie z baterii mierzone na wejściu A0 (dzielnik R4, R5 i VREF = 3.3V)

#define DS18_TEMPERATURE_CHANNEL 11
#define RN_RESET_PIN 4
#define debugSerial Serial
SoftwareSerial loraSerial(6, 7); // port do komunikacji z RN2483 (RX, TX)

// tryb OTAA - AppEUI i AppKey
const char *appEui = "0000000000000000";
const char *appKey = "00000000000000000000000000000000";

TheThingsNetwork ttn(loraSerial, debugSerial, TTN_FP_EU868, 11);

// interwał wysyłania danych w ms
const unsigned long TX_INTERVAL = 900000;

// bufor danych (maksymalnie 51 bajtów)
CayenneLPP lppdata(51);

// czujnik BME280 (I2C)
Adafruit_BME280 bme;   
bool bmeFound;

// czujnik temperatury DS18B20 (1-Wire)
OneWire ow(ONE_WIRE_BUS);
DallasTemperature ds(&ow);
bool dsFound;

unsigned long start_time;

// skanowanie magistrali 1-Wire - wyszukiwanie podłączonych czujników DS18xxx
void owScan()
{
  DeviceAddress address;
  dsFound = false;
  
  ds.begin();
  if (ds.getDeviceCount() == 0)
    return;

  for (int i = 0; i < ds.getDeviceCount(); i++)
  {
    if (ds.getAddress(address, i))
    {
      Serial.print("Device found @ ");
      for (int j = 0; j < 8; j++)
        printHex(address[j]);
      Serial.println();
    }
  }
  if (ds.getDS18Count() > 0)
    dsFound = true;
}

// pobieranie danych z czujników i wrzucanie do bufora
void getData()
{
  // czyszczenie bufora
  lppdata.reset();

  float temperature;
  // odczyt danych z czujnika BME280
  if (bmeFound)
  {
    temperature = bme.readTemperature();
    float pressure = bme.readPressure() / 100.0F; // hPa
    float humidity = bme.readHumidity();
    
    Serial.print("Temperatures (°C): ");
    Serial.println(temperature);
    Serial.print("Pressure (hPa): ");
    Serial.println(pressure);
    Serial.print("Humidity (%): ");
    Serial.println(humidity);
  
    lppdata.addTemperature(1, temperature);
    lppdata.addRelativeHumidity(2, humidity);
    lppdata.addBarometricPressure(3, pressure);
  }

  // napięcie baterii
  lppdata.addAnalogInput(4, VBAT);
  
  // odczyt danych z czujników DS18B20
  if (dsFound)
  {
    DeviceAddress address;
    int channel = DS18_TEMPERATURE_CHANNEL;
    for (int i = 0; i < ds.getDeviceCount(); i++)
    {
      if (!ds.getAddress(address, i))
        continue;
      
      if (!ds.validFamily(address))
        continue;

      ds.requestTemperaturesByAddress(address);
      temperature = ds.getTempC(address);
      if (temperature == DEVICE_DISCONNECTED_C)
        continue;
      
      Serial.print("DS18B20[");
      Serial.print(i);
      Serial.print("] temperature (°C): ");
      Serial.println(temperature);

      if (lppdata.addTemperature(channel++, temperature) == 0)
          break;
    }
  }
}

void setup()
{
  pinMode(USER_LED, OUTPUT);

  debugSerial.begin(9600);
  // oczekiwanie na Serial Monitor
  while (!debugSerial && millis() < 1000);

  Serial.println("--- START");
  
  // czujnika BME280
  if (bme.begin(0x76))
  { 
    bmeFound = true;
    Serial.println("BME280 found");
  }

  // czujniki temperatury DS18B20
  owScan();
   
  // uruchomienie komunikacji z RN2483
  loraSerial.begin(9600);
  ttn.wake();
  ttn.resetHard(RN_RESET_PIN);
  ttn.reset(false);
  ttn.onMessage(message);

  // odczyt i wyświetlanie informacji z RN2483
  Serial.println("--- STATUS");
  ttn.showStatus();

  // wyłączenie ADR
  ttn.setADR(false);
  
  // podłączenie do sieci 
  Serial.println("--- JOIN");
  ttn.join(appEui, appKey);
}

void loop() 
{
  // wysyłanie danych
  start_time = millis();
  Serial.println("--- SEND");
  digitalWrite(USER_LED, HIGH);
  getData();
  ttn.sendBytes(lppdata.getBuffer(), lppdata.getSize());
  digitalWrite(USER_LED, LOW);

#ifdef LOW_POWER
  // wprowadzenie w tryb uśpienia
  ttn.sleep((unsigned long)TX_INTERVAL);
  Serial.flush();
  for (int i = 0; i < int((TX_INTERVAL / 1000) / 8); i++) 
  {
    LowPower.powerDown(SLEEP_8S, ADC_OFF, BOD_OFF);
  }
  // wybudzenie RN2483
  ttn.wake();
#else
  while (millis() - start_time < TX_INTERVAL)
  {
    delay(1);
  }
#endif
}

static void printHex(uint8_t b) 
{
  if (b < 0x10)
    Serial.print('0');
  Serial.print(b, HEX);
}

void message(const uint8_t *payload, size_t size, port_t port)
{
  Serial.println("--- MESSAGE");
  Serial.print("Received " + String(size) + " bytes on port " + String(port) + ": ");
  for (int i = 0; i < size; i++)
  {
    printHex(payload[i]);
  }
  Serial.println();
}

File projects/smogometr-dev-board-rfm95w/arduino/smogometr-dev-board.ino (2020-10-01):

/*
 * Application template for lora-dev-board
 * ---------------------------------------
 * Board version: 1.0
 * Board config: Arduino Pro Mini + RFM95W
 * ---------------------------------------
 */
#include <lmic.h>
#include <hal/hal.h>
#include <SPI.h>
#include <SoftwareSerial.h>
#include <CayenneLPP.h>
#include <LowPower.h>

#include <BH1750.h>
BH1750 lightSensor;

//#include <i2c_BMP280.h>
#include <Adafruit_BME280.h>
Adafruit_BME280 bme280;

#include <sds.h>

// #define JUST_SEND_HELLO 
#define SAVE_ENERGY


// ------- inputs, outputs and interfaces (see lora-dev-board circuit diagram)

#define USER_LED 2 // additional LED
#define VOUT_ENABLE 3 // output voltage (TP5) control (VCC/VBAT - depends on JP9)

SoftwareSerial userSerial(8, 9); // GPSP available on J3 (RX, TX)
SDS sds(userSerial);
SDS::DATA data;

#define VBAT (analogRead(A0) * 0.00424568) // battery voltage measured on A0

// ------- LoRaWAN configuration

// ABP mode - set DevAddr and session keys
static const PROGMEM u1_t NWKSKEY[16] = { 0x20, 0x61, 0x4F, 0x03, 0xD9, 0x6F, 0x7C, 0x7E, 0xAA, 0x31, 0xBC, 0x81, 0x94, 0xBA, 0xFE, 0xAD };
static const PROGMEM u1_t APPSKEY[16] = { 0x75, 0x02, 0xED, 0x8D, 0xF2, 0xA6, 0x20, 0xB8, 0xA2, 0x2D, 0x63, 0x8C, 0xBA, 0xBA, 0x94, 0x29 };
static const u4_t DEVADDR = 0x26011FAA;

// leave empty callbacks (only used in OTAA) 
//void os_getArtEui (u1_t* buf) { }
//void os_getDevEui (u1_t* buf) { }
//void os_getDevKey (u1_t* buf) { }

// pin mapping for SX1276 (see lora-dev-board circuit diagram)
const lmic_pinmap lmic_pins = {
    .nss = 10,
    .rxtx = LMIC_UNUSED_PIN,
    .rst = 4,
    .dio = { 5, 7, LMIC_UNUSED_PIN }, // or { 5, 7, 6 } if JP3 is in DIO2 position
};

// ------- tasks, intervals, buffers, etc.

// data send task
static osjob_t sendjob;

// data send interval in seconds
const unsigned TX_INTERVAL = 900;

// data buffer
#ifdef JUST_SEND_HELLO
  static uint8_t hello[] = "Hello!";
#else
  CayenneLPP lppdata(51);
#endif

// -------  

void getData()
{
#ifndef JUST_SEND_HELLO  

  // Light sensor
  uint16_t lux = lightSensor.readLightLevel();    //odczytanie wartości z czujnika

  // odczyt czujnika BME280
  float temperature = bme280.readTemperature();
  float pressure = bme280.readPressure() / 100.0F; // hPa
  float humidity = bme280.readHumidity();

  digitalWrite(VOUT_ENABLE, HIGH);
  // SDS wake up
  sds.wakeUp();
  delay(30000); 

  // read from SDS011
  bool sds_ok = false;
  sds.requestRead();
  if (sds.readUntil(data))
  {
    sds_ok = true;
  }
  
//  // SDS sleep mode
  sds.sleep();
  digitalWrite(VOUT_ENABLE, LOW);
  
  lppdata.reset();
  // here you can read data from sensors and prepare buffer to send
  lppdata.addAnalogInput(1, VBAT); // add battery voltage
  lppdata.addTemperature(2, temperature);
  lppdata.addRelativeHumidity(3, humidity);
  lppdata.addBarometricPressure(4, pressure);
  if (sds_ok) 
  {
    lppdata.addAnalogInput(5, data.pm_25 / 10.0);
    lppdata.addAnalogInput(6, data.pm_100 / 10.0);
  }
  lppdata.addLuminosity(7, lux);

#endif
}

void do_send(osjob_t* j)
{ 
  Serial.println("--- SEND");
  if (LMIC.opmode & OP_TXRXPEND) 
  {
    Serial.println(F("OP_TXRXPEND, not sending"));
  } 
  else 
  {
    digitalWrite(USER_LED, HIGH);
#ifdef JUST_SEND_HELLO
    LMIC_setTxData2(1, hello, sizeof(hello) - 1, 0);
#else 
    getData();
    LMIC_setTxData2(1, lppdata.getBuffer(), lppdata.getSize(), 0);
#endif
    Serial.println(F("Packet queued"));
  }
}

void onEvent(ev_t ev) 
{
//  Serial.print(os_getTime());
//  Serial.print(": ");
  switch(ev) 
  {
    case EV_SCAN_TIMEOUT:
      Serial.println(F("EV_SCAN_TIMEOUT"));
      break;
    case EV_BEACON_FOUND:
      Serial.println(F("EV_BEACON_FOUND"));
      break;
    case EV_BEACON_MISSED:
      Serial.println(F("EV_BEACON_MISSED"));
      break;
    case EV_BEACON_TRACKED:
      Serial.println(F("EV_BEACON_TRACKED"));
      break;
    case EV_JOINING:
      Serial.println(F("EV_JOINING"));
      break;
    case EV_JOINED:
      Serial.println(F("EV_JOINED"));
      break;
    case EV_RFU1:
      Serial.println(F("EV_RFU1"));
      break;
    case EV_JOIN_FAILED:
      Serial.println(F("EV_JOIN_FAILED"));
      break;
    case EV_REJOIN_FAILED:
      Serial.println(F("EV_REJOIN_FAILED"));
      break;
    case EV_TXCOMPLETE:
      Serial.println(F("EV_TXCOMPLETE (includes waiting for RX windows)"));
      if (LMIC.txrxFlags & TXRX_ACK)
      {
        Serial.println(F("Received ack"));
      }
      if (LMIC.dataLen) 
      {
        Serial.println("--- MESSAGE");
        uint8_t port = LMIC.frame[LMIC.dataBeg - 1];
        Serial.print(F("Received "));
        Serial.print(LMIC.dataLen);
        Serial.print(F(" bytes on port "));
        Serial.print(port);
        Serial.print(": ");
        for (int i = 0; i < LMIC.dataLen; i++)
        {
          Serial.print(LMIC.frame[LMIC.dataBeg + i], HEX);
        }
        Serial.println();
      }
      digitalWrite(USER_LED, LOW);
#ifdef SAVE_ENERGY
      Serial.flush();
      for (int i = 0; i < int(TX_INTERVAL/8); i++) 
      {
        LowPower.powerDown(SLEEP_8S, ADC_OFF, BOD_OFF);
      }
      do_send(&sendjob);
#else
      os_setTimedCallback(&sendjob, os_getTime()+sec2osticks(TX_INTERVAL), do_send);
#endif
      break;
    case EV_LOST_TSYNC:
      Serial.println(F("EV_LOST_TSYNC"));
      break;
    case EV_RESET:
      Serial.println(F("EV_RESET"));
      break;
    case EV_RXCOMPLETE:
      Serial.println(F("EV_RXCOMPLETE"));
      break;
    case EV_LINK_DEAD:
      Serial.println(F("EV_LINK_DEAD"));
      break;
    case EV_LINK_ALIVE:
      Serial.println(F("EV_LINK_ALIVE"));
      break;
    default:
      Serial.println(F("Unknown event"));
      Serial.println((unsigned) ev);
      break;
  }
}
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

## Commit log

2020-05-05 Add pcb-overview.png
2020-05-18 dodanie wersji v1.1
    [LORA_BOARD.kicad_pcb, LORA_BOARD.sch]
2020-05-21 Poprawienie opisu włącznika zasilania; Dodanie plików produkcyjnych GERBER.
    [LORA_BOARD.kicad_pcb]
2021-01-04 -Zmiany w schemacie: -Usunięte połączenia z RN do header'ów, zastąpione TestPoint'ami -Aktualizacja projektu płytki
    [OSR_RN.kicad_pcb, OSR_RN.sch]
2021-01-14 Przeorganizowanie ścieżek.
    [OSR_RN.kicad_pcb]
2021-02-16 SCH: -kosmetyka PCB: -Zmiana złącz baterii i panelu fotowoltaicznego na raster 2.5mm (JST). -Zmiana obudowy diod zabezpieczających. -Kosmetyka
    [OSR_RN.kicad_pcb, OSR_RN.sch]
2021-02-19 Zmiana złącza USB Zmiana złącz baterii i panelu fotowoltaicznego Dodanie opisów Kosmetyka
    [OSR_RN.kicad_pcb, OSR_RN.sch]
2021-02-20 Uzupełnienie bibliotek, footprintów oraz modeli 3D
2024-11-25 Add battery voltage measurement
2025-03-10 Add case files & readme.
    [Podstawa.stl]
2025-08-01 Added resetting after every boot. Prevents hang on initialization of RN chip.
    [weather-station.ino]
